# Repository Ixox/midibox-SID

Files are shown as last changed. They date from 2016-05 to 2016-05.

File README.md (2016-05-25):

# midibox-SID
PCBs, Panels and firmware for puting a 4 stereo voices midiboxSid in a 1U 19" rack

Contains all files needed for this project : 
http://midibox.org/forums/topic/20008-midibox-sid-rack-1u-project/

SID_CS/
Kicad files for the 1st surface control PCB

SID_CS2/
Kicad files for the 2nd surface control PCB

SID_MB/
Kicad files for the mother board

SID_MIXER/
Kicad files for the mixer PCB

midibox_sid_v2_044_rack1U/
Firmware: Thorsten source code with some modification for the rack 1U PCBs

pfm2_lib.pretty/
Kicad library

shaeffer/
Front Panel Designer files that work with this 1U rack : 
http://www.frontpanels.de/nrg-case-19-enclosures/

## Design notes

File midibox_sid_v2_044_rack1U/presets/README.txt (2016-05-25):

$Id: README.txt 398 2008-07-26 14:40:52Z tk $

This package contains the preset patches for MIDIbox SID V2:

   o v2_vintage_bank.syx:
     Based on "midibox_sid_presets_8580.syx" of the MBSID V1 preset library,
     converted with the patch converter which can be found in the tools/
     directory. The results have been manually improved by TK to take new
     V2 features into account.

Currently there is no special SysEx upload tool available for MIDIbox
SID V2. Please use a SysEx tool like MIDI-Ox, and configure a delay of
750 mS between SysEx strings (MIDI-Ox: SysEx->Configure, set "Delay after
F7 to 750 mS)

Following preset patches are available:
--------------------------------------------------------------------------------------------
001 Internal Patch      033 Drum Kit 1          065 ARPSEQ One B        097 Monty Lead3
002 Techno PWM          034 Drum Kit 2          066 ARPSEQ One C        098 Monty Lead4
003 Techno Saw          035 Drum Kit 3          067 SEQ TranceBass      099 Bassline Demo1
004 Techno 5th          036 Drum Kit 4          068 SEQ Vintage A       100 Bassline Demo2
005 Cool Brass          037 Some Triggs         069 SEQ Vintage B       101 Vib Synth
006 Simple Saw          038 More Triggs         070 SEQ Vintage C       102 Whats That?
007 Simple Pulse        039 RingModMod          071 ARPSEQ Two A        103 Sample&Hold 1
008 Pulse w/o Body      040 RampUp              072 ARPSEQ Two B        104 Sample&Hold 2
009 Popcorn             041 Math Game           073 ARPSEQ Two C        105 Curve Filter D
010 WT Flute            042 WT Runner           074 ARPSEQ Three        106 Curve total
011 Synth Plug          043 WT Stereo Echo      075 ARPSEQ Four         107 Poly Trancegate
012 WT Synth            044 Turntable           076 SEQ Mighty Bass     108 Zak Bass
013 WT HardcoreSynth    045 Driving a Car       077 Analog Dream1       109 Zak Bass 2
014 Sync Sound          046 Ufo Reverse         078 Analog Dream2       110 Kik A
015 Sync Pad            047 WT Falling          079 Analog Dream3       111 Cymbal A
016 Filt. Poly Pad      048 WT Helicopter       080 Analog Dream4       112 Cymbal B
017 Filt. Mono Pad      049 WT Neutron          081 Analog Dream5       113 Hat A
018 Arpeggio            050 WT Filtered Seq.    082 PWM Bass1           114 Snare A
019 Arpeggio 2          051 Alien Groove        083 PWM Bass2           115 Accomp A
020 WT Arp Fun          052 Nice Lead           084 PWM Bass3           116 Accomp B
021 Ringmodulation      053 NT Bass             085 PWM Bass4           117 Lead Stacco1
022 Filtered B. 6581    054 RingKabinett        086 Seq Bass1           118 Lead Stacco2
023 Filtered B. 8580    055 Random Fun          087 Seq Bass2           119 Lead Melodia
024 Filtered Bass 2     056 Don't cry baby!     088 Seq Bass3           120 Stacco4
025 C64 Bass            057 Tweak the LFOs      089 Seq Bass4           121 String Ponte 1
026 Autobahn            058 Random Sync         090 Seq Bass5           122 String Ponte 2
027 Bassdrum            059 A stormy Day        091 Seq Bass6           123 Crescendo
028 Bassdrum2           060 6 Octave Plug       092 Monty Bass1         124 Crazy Lead
029 Cymbal              061 Poly Saw            093 Monty Bass2         125 Accomp1
030 Klick               062 Step by Step        094 Monty Bass3         126 Casio Drums
031 Metal               063 Slow Intro          095 Monty Lead1         127 Classic Zelda
032 Deep Bass 9         064 ARPSEQ One A        096 Monty Lead2         128 Neo Zelda
--------------------------------------------------------------------------------------------

Patch 001-107 made by Thorsten Klose (2002-2004)
Patch 108-125 made by Matteo Bosi (2003-2004)
Patch 126-128 made by David Panseri (2004)

--------------------------------------------------------------------------------------------

ChangeLog:
~~~~~~~~~~

2008-07-26:
   o overworked patches for v2.0RC24 engine

2008-03-27:
   o replaced Placeholders A035 and A036 by new Drum Kits
   o replaced Placeholders A037..A044 by new trigger and modulation matrix examples
   o Patch A089-A91 (not working "Miami1"..3) replaced by "SEQ Bass 4"..6
   o Patch A103 and A104 (not working "WT Pseudo S&H") replaced by "Sample&Hold 1" and 2
   o Patch A107 (not working "WT Flip LFO") replaced by "Poly Trancegate"

2007-09-29:
   o Patch A033 and A034 replaced by Drum Kits + Sequences
   o Patch A035..A044 (expired WT drum patches) replaced by placeholders

2007-07-22:
   o Patch A099 and A100 replaced by Bassline demo sequences
     Recommented Ensemble configuration (Ensemble->INS)
       - Ins1 and Ins2 assigned to same MIDI channel
       - Ins1 splitpoints SpL: c-2, SpU: B-3
       - Ins2 splitpoints SpL: C-4, SpU: G-8
     Note that the second bassline can only be played if
     a second MBHP_SID module is connected to the core.

     Optionally within Ensemble->Clk the MIDI Slave function 
     can be activated.

2007-06-30:
   o released converted bank A for MIDIbox SID V2
	
2006-08-20:
   o new Patches C038-C048 made by Sebastian (aka Rio)
   o new Patches C049-C055 made by TK (they demonstrate the
     possibilities of the V1.7303 sound engine)
   o A018 (Arpeggio): changed Arp speed from 110 to 70
   o A019 (Arpeggio2): changed Arp speed from 110 to 70/90

2006-02-27:
   o new Patches C006-C037 made by Sebastian (aka Rio)

2005-11-09:
   o A018 (Arpeggio): changed Arp speed from 99 to 110
   o A052 (Nice Lead): changed Portamento speed from 66 to 30
   o A067 (SEQ TranceBass): optimized Attack/Decay/Curve of ENV1,
                            activated HP filter in addition
   o A074 (ARPSEQ Three): activated oscillator phase synchronization
   o A076 (SEQ Mighty Bass): changed ENV1 depth from 14 to 33
   o A078 (Analog Dream 2): increased Release of VCA ENVs
   o A080 (Analog Dream 4): increased Release of VCA ENVs
   o A089-A091 (Miami *): set volume to 80
   o A093/A094 (Monty Bass *): increased CutOff
   o A105 (Curve Filter D): increased CutOff
   o added Patch C006-C011 made by Sebastian (aka Rio)

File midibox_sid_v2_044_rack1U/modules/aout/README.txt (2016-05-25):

$Id: README.txt 1121 2013-04-16 20:18:49Z tk $

Driver for AOUT modules
=======================

Oversight
~~~~~~~~~

This driver provides functions to access DACs which are used in
the MIDIbox hardware platform (MBHP) to output analog control
voltages (MBHP_AOUT*).

The API is identical for all AOUT modules to allow highest flexibility. New
transfer protocols can be added w/o touching an existing application.

DAC and CS/CLK/DIN pin have to selected from the Makefile/Assembly source
during compile time.

Implementation Concept
~~~~~~~~~~~~~~~~~~~~~~

The application interface (API) has been tailored around AOUT modules, which
are part of the MIDIbox Hardware Platform (MBHP), and MIOS based applications
like MIDIbox CV (CV control via MIDI), MIDIbox SEQ (CV control from a 
sequencer) and MIDIbox SID/FM (CV control from a synthesizer)

Up to 8 analog outputs are supported (*)
An interface to control digital pins is available as well (**)

Output voltages are managed in 16bit resolution. Although none of the current
modules support the full resolution, from programming and performance
perspective it makes sense to organize CV values this way.

An additional function for setting pins in 7bit resolution is available,
which left-aligns the value to the 16bit format. The usage of this function is 
prefered for applications which are working at common MIDI resolution.

Before voltage changes are transfered to the external hardware, the 
AOUT_Pin16bitSet/AOUT_Pin7bitSet function compares the new value with the 
current one. If equal, the register transfer will be omitted, otherwise it
will be requested and performed once AOUT_Update() is called.

This method has two advantages:
   - if AOUT_Pin*bitSet doesn't notice value changes, the appr. AOUT channels
     won't be updated to save CPU performance
   - all CV pins will be updated at the same moment

(*) currently only limited by the AOUT_UPDATE_REQ variable. This could be enhanced 
in future if really required, but this would cost performance!

(**) currently only supported for MBHP_AOUT, since MAX525 provides such a digital output pin

Supported AOUT interfaces
~~~~~~~~~~~~~~~~~~~~~~~~~

AOUT_INTERFACE_TYPE == 0
   selects a dummy module which with empty function stubs (-> no external accesses)

AOUT_INTERFACE_TYPE == 1
   CV: up to 2 cascaded MAX525 (MBHP_AOUT module), each MAX525 provides 
   4 channels with 12bit resolution
   Digital: 1 pin per IC

AOUT_INTERFACE_TYPE == 2
   CV: up to 8 cascaded 74HC595 (each MBHP_AOUT_LC module provides 2 74HC595)
       resolution is selectable with AOUT_LC_RESOLUTION_OPTION_M1 .. 4:
       AOUT_LC_RESOLUTION_OPTION_Mx == 0: 12/4 bit configuration
       AOUT_LC_RESOLUTION_OPTION_Mx == 1: 8/8 bit configuration
       AOUT_LC_RESOLUTION_OPTION_Mx == 2: combines 4 shift registers. The first
          two SRs are working like option 0 (12/4). The third SR outputs the 
          lower bits of second channel, and the fourth SR the 8bit value of 
          third channel.
          The fourth channel value is ignored by this configuration
          (same for channel 4-7: channel 8 igored)
          For this "combined" option, it is recommented to set both modes
          (M1,M2 and/or M3/M4) to value 2 for future compatibility
   Digital: none

AOUT_INTERFACE_TYPE == 3
   CV: one TLV5630 (MBHP_AOUT_NG module) with 8 channels at 12bit resolution
   Digital: none

C usage examples
~~~~~~~~~~~~~~~~

  -> $MIOS_PATH/apps/processing/analog_toolbox

Assembler usage examples
~~~~~~~~~~~~~~~~~~~~~~~~

  -> $MIOS_PATH/apps/processing/midibox_cv
  -> $MIOS_PATH/apps/sequencers/*
  -> $MIOS_PATH/apps/synthesizers/*

Functions
~~~~~~~~~

See aout.inc for function descriptions
See aout.h for C declarations

Files
~~~~~

  aout.inc: toplevel of AOUT driver. Can be included into "asm-only" programs (non-relocatable code)
  sdcard.asm: relocatable wrapper for C based applications
  aout.h:   C header
  aout.mk:  include this into Makefile to integrate the module
  aout_*.inc: low-level drivers for the selected interface

Defines
~~~~~~~

  C programs (relocatable code): can be overruled with -D<define>=<value> from command line 
  Assembly programs: add #define statements within program before "#include <aout.inc>"

AOUT_INTERFACE_TYPE     ; 0..3, see description above

AOUT_LC_RESOLUTION_OPTION_M1  ; 0..2, see description above
AOUT_LC_RESOLUTION_OPTION_M2
AOUT_LC_RESOLUTION_OPTION_M3
AOUT_LC_RESOLUTION_OPTION_M4

AOUT_LAT_CS=LATC	; The chip select pin
AOUT_TRIS_CS=TRISC	; is connected to Port C.5
AOUT_PIN_CS=5		; (CANNOT be shared with other outputs!)

AOUT_LAT_DIN=LATC	; The data input pin DIN
AOUT_TRIS_DIN=TRISC	; is connected to Port C.4
AOUT_PIN_DIN=4		; (can be shared with other outputs)

AOUT_LAT_SCLK=LATD	; The shift clock input pin SCLK
AOUT_TRIS_SCLK=TRISD	; is connected to Port D.5
AOUT_PIN_SCLK=5		; (can be shared with other inputs)

Integration Hints
~~~~~~~~~~~~~~~~~

C based Applications
~~~~~~~~~~~~~~~~~~~~

  1) Makefile: add "aout.o" to OBJS variable

  2) Makefile: include aout.mk, and enhance AOUT_DEFINES if required:
---

# include SD Card Driver
# use following pin assignments:
AOUT_DEFINES += -DAOUT_INTERFACE_TYPE=1
AOUT_DEFINES += -DAOUT_LAT_CS=LATC -DAOUT_TRIS_CS=TRISC -DAOUT_PIN_CS=0
AOUT_DEFINES += -DAOUT_LAT_DIN=LATC -DAOUT_TRIS_DIN=TRISC -DAOUT_PIN_DIN=4
AOUT_DEFINES += -DAOUT_LAT_SCLK=LATD -DAOUT_TRIS_SCLK=TRISD -DAOUT_PIN_SCLK=5
include $(MIOS_PATH)/modules/aout/aout.mk
---

  3) main.c: #include <aout.h>

  4) main.c: add following code to Init() hook
---
  // initialize AOUT driver
  AOUT_Init();
---

  5) main.c: add following code to Tick() hook
---
  // update AOUT channels
  AOUT_Update();
---

"Assembler-Only" Applications
~~~~~~~~~~~~~~~~~~~~~~~~~~~~~

integration is possible, but not documented yet
However, most applications like MBCV, MBSID, MBFM, MBSEQ are using this driver!

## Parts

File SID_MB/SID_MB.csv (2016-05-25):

Reference | Value | Footprint | Datasheet
SID1 | 8580 | Housings_DIP:DIP-28_W15.24mm_LongPads
pic1 | PIC18f452 | Housings_DIP:DIP-40_W15.24mm
shft1 | 74HC595 | Housings_DIP:DIP-16_W7.62mm_LongPads
shft2 | 74HC595 | Housings_DIP:DIP-16_W7.62mm_LongPads
U2 | 24C512 | Housings_DIP:DIP-8_W7.62mm
U4 | 24C512 | Housings_DIP:DIP-8_W7.62mm
U5 | 24C512 | Housings_DIP:DIP-8_W7.62mm
C1 | LCD | Pin_Headers:Pin_Header_Straight_2x08
P3 | MEM | Pin_Headers:Pin_Header_Straight_2x02
C4 | 22nF | Capacitors_ThroughHole:C_Rect_L4_W2.5_P2.5
C5 | 22nF | Capacitors_ThroughHole:C_Rect_L4_W2.5_P2.5
P4 | SID_MEM | Pin_Headers:Pin_Header_Straight_1x02
R2 | 1k | Resistors_ThroughHole:Resistor_Horizontal_RM7mm
R4 | 100 | Resistors_ThroughHole:Resistor_Horizontal_RM7mm
C9 | 100nF | Capacitors_ThroughHole:C_Rect_L4_W2.5_P2.5
C10 | 100nF | Capacitors_ThroughHole:C_Rect_L4_W2.5_P2.5
C11 | 100nF | Capacitors_ThroughHole:C_Rect_L4_W2.5_P2.5
C12 | 100nF | Capacitors_ThroughHole:C_Rect_L4_W2.5_P2.5
P10 | IN1 | Pin_Headers:Pin_Header_Straight_1x02
P11 | IN2 | Pin_Headers:Pin_Header_Straight_1x02
P12 | STEREO OUT | Pin_Headers:Pin_Header_Straight_1x04
R9 | 1k | Resistors_ThroughHole:Resistor_Horizontal_RM7mm
C16 | 470pF | Capacitors_ThroughHole:C_Rect_L4_W2.5_P2.5
C14 | 1nF | Capacitors_ThroughHole:C_Rect_L4_W2.5_P2.5
Q1 | BC547 | TO_SOT_Packages_THT:TO-92_Molded_Narrow
C17 | 470pF | Capacitors_ThroughHole:C_Rect_L4_W2.5_P2.5
C15 | 1nF | Capacitors_ThroughHole:C_Rect_L4_W2.5_P2.5
Q2 | BC547 | TO_SOT_Packages_THT:TO-92_Molded_Narrow
C2 | 33pF | Capacitors_ThroughHole:C_Rect_L4_W2.5_P2.5
Y1 | 10Mhz | Crystals:Crystal_HC49-U_Vertical
C3 | 33pF | Capacitors_ThroughHole:C_Rect_L4_W2.5_P2.5
P7 | Midi Out | Pin_Headers:Pin_Header_Straight_1x03
P8 | Midi In | Pin_Headers:Pin_Header_Straight_1x03
R5 | 1k | Resistors_ThroughHole:Resistor_Horizontal_RM7mm
R6 | 1k | Resistors_ThroughHole:Resistor_Horizontal_RM7mm
R10 | 1k | Resistors_ThroughHole:Resistor_Horizontal_RM7mm
R7 | 10k | Resistors_ThroughHole:Resistor_Horizontal_RM7mm
R8 | 10k | Resistors_ThroughHole:Resistor_Horizontal_RM7mm
R14 | 220 | Resistors_ThroughHole:Resistor_Horizontal_RM7mm
R15 | 220 | Resistors_ThroughHole:Resistor_Horizontal_RM7mm
R16 | 220 | Resistors_ThroughHole:Resistor_Horizontal_RM7mm
D1 | 1N4148 | Diodes_ThroughHole:Diode_DO-35_SOD27_Horizontal_RM10
R12 | 1.2k | Resistors_ThroughHole:Resistor_Horizontal_RM7mm
R13 | 5.6k | Resistors_ThroughHole:Resistor_Horizontal_RM7mm
RV1 | POT | Encoder:FMRV
R11 | 68 | Resistors_ThroughHole:Resistor_Horizontal_RM7mm
P2 | MEM_sel | Pin_Headers:Pin_Header_Straight_2x02
U3 | 24C512 | Housings_DIP:DIP-8_W7.62mm
P13 | J11 | Pin_Headers:Pin_Header_Straight_1x02
P14 | CAN | Pin_Headers:Pin_Header_Straight_1x02
R17 | 1k | Resistors_ThroughHole:Resistor_Horizontal_RM7mm
D2 | 1N4148 | Diodes_ThroughHole:Diode_DO-35_SOD27_Horizontal_RM10
C6 | 22nF | Capacitors_ThroughHole:C_Rect_L4_W2.5_P2.5
C7 | 22nF | Capacitors_ThroughHole:C_Rect_L4_W2.5_P2.5
R1 | 1k | Resistors_ThroughHole:Resistor_Horizontal_RM7mm
opt2 | 6n138 | Housings_DIP:DIP-8_W7.62mm
P6 | J9 J8 | Pin_Headers:Pin_Header_Straight_2x05
C13 | 100nF | Capacitors_ThroughHole:C_Rect_L4_W2.5_P2.5
SID2 | 8580 | Housings_DIP:DIP-28_W15.24mm_LongPads
P1 | 9V | Connect:bornier2
P9 | 5v | Connect:bornier2
CP1 | 10uF | Capacitors_ThroughHole:C_Radial_D5_L6_P2.5
CP2 | 10uF | Capacitors_ThroughHole:C_Radial_D5_L6_P2.5
R3 | 10k | Resistors_ThroughHole:Resistor_Horizontal_RM7mm
C8 | 100nF | Capacitors_ThroughHole:C_Rect_L4_W2.5_P2.5
C18 | 100nF | Capacitors_ThroughHole:C_Rect_L4_W2.5_P2.5
H1 | 3mmHole | Mounting_Holes:MountingHole_3.2mm_M3
H2 | 3mmHole | Mounting_Holes:MountingHole_3.2mm_M3
H3 | 3mmHole | Mounting_Holes:MountingHole_3.2mm_M3
H4 | 3mmHole | Mounting_Holes:MountingHole_3.2mm_M3
CP3 | 1uF | Capacitors_ThroughHole:C_Radial_D5_L6_P2.5
CP4 | 1uF | Capacitors_ThroughHole:C_Radial_D5_L6_P2.5
C20 | 1nF | Capacitors_ThroughHole:C_Rect_L4_W2.5_P2.5
C19 | 1nF | Capacitors_ThroughHole:C_Rect_L4_W2.5_P2.5
DB1 | Diode_Bridge | Gajda_power:Bridge-rond
CP5 | 2200uF | Capacitors_ThroughHole:C_Radial_D12.5_L25_P5
C21 | 330nF | Capacitors_ThroughHole:C_Rect_L4_W2.5_P2.5
CP6 | 10uF | Capacitors_ThroughHole:C_Radial_D5_L6_P2.5
C22 | 100nF | Capacitors_ThroughHole:C_Rect_L4_W2.5_P2.5
DB2 | Diode_Bridge | Gajda_power:Bridge-rond
CP7 | 2200uF | Capacitors_ThroughHole:C_Radial_D12.5_L25_P5
C23 | 330nF | Capacitors_ThroughHole:C_Rect_L4_W2.5_P2.5
CP8 | 10uF | Capacitors_ThroughHole:C_Radial_D5_L6_P2.5
C24 | 100nF | Capacitors_ThroughHole:C_Rect_L4_W2.5_P2.5
U6 | 7809 9v | Power_Integrations:TO-220
U1 | 7805 5v | Power_Integrations:TO-220
P15 | 9VOnly | Pin_Headers:Pin_Header_Straight_1x02
P5 | J5A | Pin_Headers:Pin_Header_Straight_2x06
P16 | J5B | Pin_Headers:Pin_Header_Straight_1x03

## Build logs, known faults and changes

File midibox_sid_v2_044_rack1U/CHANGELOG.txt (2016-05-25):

$Id: CHANGELOG.txt 1189 2014-12-19 20:00:14Z tk $

MIDIboxSID V2.044
~~~~~~~~~~~~~~~~~

   o This version got an improved rotary encoder handling.
     Please update to MIOS V1.9h before uploading the application, otherwise the improvements
     won't be effective.

   o swapped behaviour of ENC speed control again, so that encoders are at fast speed
     by default, and slow if SHIFT button pressed.
     This behaviour can now be alternated in your setup_*.asm file by changing
     the DEFAULT_SHIFT_SPEED_CONTROL_MODE option

   o implemented special encoder testmode which can be enabled with
     DEFAULT_TESTMODE_ENC_SPEED in the setup_*.asm file

   o envelopes are now released properly when a note is played via the SysEx editor
     (or with the PLAY button)

   o added new "SuperSaw" detune mode which has been created by Lis0r.
     In distance to the normal (legacy) mode, results are much better especially on
     higher detune values!
     The detune mode (DtM) can be selected in the OSC page for lead engine patches, and
     in the O23 page for bassline patches.

MIDIboxSID V2.043
~~~~~~~~~~~~~~~~~

   o fixed NRPN handling for Multi patches

   o implemented CCs for Bassline/Drum/Multi Engine
     See doc/mbsidv2_cc_chart.txt for available CCs

   o display updated when the patch name has been changed from external

MIDIboxSID V2.042
~~~~~~~~~~~~~~~~~

  o new SysEx commands to support the Lemur Editor

  o MIDI Clock is now optionally sent with the "Out" option of the Ensemble Clk page.

  o default encoder mode is "DETENTED3" now, since it works better for most encoders
    available on the market

  o swapped behaviour of ENC speed control: encoder now at fast speed if SHIFT button is pressed

MIDIboxSID V2.041
~~~~~~~~~~~~~~~~~

  o corrected sysex handling for MIOS Studio SysEx Librarian

MIDIboxSID V2.040
~~~~~~~~~~~~~~~~~

  o fixed SysEx patch write issue which happened when patches were received
    with the common format (e.g. preset patches)

MIDIboxSID V2.039
~~~~~~~~~~~~~~~~~

  o LFO MIDI Clock Sync has been overworked, it now supports 32 different
    rates from 16 bars to 1/32 notes including triple and dotted delays!

    If the CSn flag enabled the available rates are:
    0=LFO disabled, 8=16 bars, 16=14 bars, 24=12 bars, 32=10 bars,
    40=9 bars, 48=8 bars, 56=7 bars, 64=6 bars, 72=5 bars, 80=4 bars,
    88=3.5 bars, 96=3 bars, 104=2.5 bars, 112=2 bars, 120=1.5 bars,
    128=1 bar, 136=1/2., 144=1/1T, 152=1/2, 160=1/4., 168=1/2T,
    176=1/4, 184=1/8., 192=1/4T, 200=1/8, 208=1/16., 216=1/8T,
    224=1/16, 232=1/32., 240=1/16T, 248=1/32

    Note that in MIDI Sync mode, the LFO Delay won't work because
    the appr. resource is used as MIDI clock counter.

  o current bank and patch number won't be changed anymore on direct RAM
    access via SysEx

MIDIboxSID V2 RC38
~~~~~~~~~~~~~~~~~~

  o optimized MBNet Handler for fast external access to SID registers

  o added DEFAULT_CC32_FILTER switch to setup_*.asm - it filters CC#32 for
    programs which send this CC always together with CC#0 on bank changes

  o support for "extended SysEx dump" - see also mbsidv2_sysex_implementation.txt

  o filter mode/channel and waveform flags can now be optionally passed to 
    J5 (configuration has to be done in setup_*.asm file)

  o (only for Multi Engine): "W+16" flag - waveform can be changed from
    offset +16 of the wavetable, in combination with another parameter
    (such as #249), it's possible to control pitch and waveform from
    a single WT track

MIDIboxSID V2 RC37
~~~~~~~~~~~~~~~~~~

  o SW based feedback loops won't lead to endless repeated replies

MIDIboxSID V2 RC36
~~~~~~~~~~~~~~~~~~

  o Bassline engine: detune parameter now mapped to Parameter #003
  o a table based calibration table is now provided for the SID filter.
    It has to be adapted under src/sid_filter_table.inc and can either be
    uploaded together with the firmware build, or separately if by uploading
    "sid_filter_table.hex" after the "make" command (type "make sid_filter_table"
    to build only this file)
    The table can be used to compensate technology related non-linearities
    of the 6581 R-2R DAC
  o various minor bugfixes

MIDIboxSID V2 RC35
~~~~~~~~~~~~~~~~~~

  o modulation source "KEY" now uses current frequency instead of key number
    to consider frequency sweeps correctly
  o bugfix for "jump to page" (empty page if current item position outside new page)
  o bugfix for knob page (min/max value modified Pa1 if multiple SIDs selected)

MIDIboxSID V2 RC34
~~~~~~~~~~~~~~~~~~

  o fixed race condition in SusKey portamento function
  o Note Off keys which are not in the note stack are ignored now
  o implemented CC#123 (All Notes Off)
    Complies to MIDI spec. Means: only CC#123=0 will unplay all notes,
    all other values (1..127) are silently ignored
  o new wavetable control function "Key" allows to select a wavetable
    step with the currently played note inside the given Begin/End range.
    E.g., with Begin=0x00, End=0x7f, KEY=on, Par=200 you are able to
    define different ENV1 Decay parameters for each note.
    There are much more usecases of course (e.g. different LFO values,
    different waveforms, Sync/Ring enable/disable in certain keyranges)
    - be creative :)
  o Arpeggiator "Easy Chord" function now active in default Lead/Bassline/Multi
    patch
  o sammichSID: F2 button now jumps to Knob page by default (especially
    nice for bassline patches, for other engines the knob assignments
    are mostly not preconfigured)
  o Multi Engine: Knob parameter #6 and #7 now allow to control CutOff
    frequency of left/right channel SID separately. Note that this isn't
    consistent to Lead/Bassline assignments, but unfortunately there is
    no other possible solution.
  o filter page now allows direct L/R channel selection
  o the full control surface now handles the first press of Osc Select, 
    Env Select, LFO Select and Filter Mode/Channel Select as a 
    "jump to page" function if that page was not displayed, and 
    thereafter, function as a "change selection" function. Thus 
    if you are not on the LFO page, pressing LFO Select jumps to 
    LFO page, and then pressing it again will change the selected LFO.
  o this is the christmas edition, therefore the Matrix LEDs are flickering
    during startup ;-)

MIDIboxSID V2 RC33
~~~~~~~~~~~~~~~~~~

  o built for MIOS V1.9g (or higher) to support new encoder types.
    Rotary encoders won't work with older MIOS versions!
    Note that MIOS only has to be updated on the master SID, as encoders
    are not connected to SID slaves anyhow.
  o a new LED matrix visualisation mode for sammichSID has been added
    which is selected with DEFAULT_LEDMATRIX_MODE 2
    - Lead and Bassline engine: 6x8 LEDs show VU meters for OSC frequency
    - Multi and Drum engine: 6x8 LEDs show animated VU meters for OSC triggers
    - ASID player mode: 6x8 LEDs show animated VU meters for OSC triggers
  o animated VU meters are a bit faster now
  o a special configuration file and prebuilt binary for sammichSID 
    is now part of the release package -> setup_sammich_sid.hex

MIDIboxSID V2 RC32
~~~~~~~~~~~~~~~~~~

  o fixed strange Oct display output in Bassline Sequence Editor
  o added "DEFAULT_ENABLE_UPPER_WAVEFORMS" switch to setup_* files to enable the
    selection of additional waveforms for SwinSID
  o overworked Meter display mode in Bassline Mode (enjoy the effect! :)
  o changed behaviour of Play button: now it plays all SIDs regardless if they
    are selected or not.
    Dedicated SIDs can be played by pressing & holding the appr. SID buttons
    before pressing PLAY

MIDIboxSID V2 RC31
~~~~~~~~~~~~~~~~~~

  o fixed storing ensemble in internal EEPROM if no BankStick selected
  o the ensemble stored in internal EEPROM (previously called E001) is now called EInt
  o the patch stored in internal EEPROM (previously called [A-H]001) is now called PInt
  o EInt now automatically selected after startup if no ensemble BankStick connected
  o E002 now automatically selected after startup if EInt was selected before
  o fix for communication with Rutger's SysEx editor: mod matrix direct assignments
    are handled correctly now in stereo edit mode

MIDIboxSID V2 RC30
~~~~~~~~~~~~~~~~~~

  o fixed OSC button behaviour (OSC selection corrupted on page changes)

MIDIboxSID V2 RC29
~~~~~~~~~~~~~~~~~~

  o fixed CC#07 (now controls volume as intended)
  o for 4x20 LCD: MIDI channels and Engines of selected ensemble are displayed at upper line
  o OSC button now cycles between 1--, -2-, --3 and 123
  o added optional CS_MENU_BUTTON_Arp function, which can be assigned to a button in setup_*.asm

MIDIboxSID V2 RC28
~~~~~~~~~~~~~~~~~~

  o fixed arpeggiator note handling bug
  o arpeggiator: the previously hardcoded "experimental arp behaviour" switch is now 
    available as software controlable switch called "Easy Chord".
    It has to be enabled in the ARP menu ("Esy" flag)
    Difference compared to normal chord entry: depressed keys will still
    be cylced by the arpeggiator until a new key is pressed.
    This feature is especially useful when slow arpeggios are played, since
    it avoids unintended "long notes" on chord changes.
    It is not useful if you intend to play a voice like a common lead instrument,
    which should turn into a fast arpeggio when more than one key is played
    (in this case, ensure that the "Esy" switch is disabled)
  o fixed drum model handling (listen to the drum patches again - they sound much better now :)
  o preliminary support for parameter access via 7bit CC
    (only available for Lead Engine yet)

MIDIboxSID V2 RC27
~~~~~~~~~~~~~~~~~~

  o Super Poly voice queue now handled centrally from master.
    Slaves notes are triggered via MBNet
  o SPV value now changed simultaneously for all slaves
    It can only be changed if master SID selected
  o PLAY button now plays a chord in superpoly mode
  o Mod matrix changes forwarded to all selected SIDs

MIDIboxSID V2 RC26
~~~~~~~~~~~~~~~~~~

  o various improvements for Super Poly Mode and SysEx distribution via CAN

MIDIboxSID V2 RC25
~~~~~~~~~~~~~~~~~~

  o improved "SusKey" (fingered portamento) handling

MIDIboxSID V2 RC24
~~~~~~~~~~~~~~~~~~

  o voice allocation of multi engine working again
  o Lead engine: MdW (ModWheel) and Key modulation source now provide a value in
    positive range only
  o overworked oscillator pitch handling: now completely linear frequency
    calculations. 
    Advantages:
      - modulation frequency (e.g. LFO vibrato) independent from oscillator frequency
      - accurate filter key tracking
      - the O2A option (forward pitch to AOUT) doesn't result into out-of-scale
        SID frequencies anymore
  o the presets under presets/v2_vintage_bank.syx have been overworked according to
    the new osc frequency handling

MIDIboxSID V2 RC23
~~~~~~~~~~~~~~~~~~

  o finetune is working properly again

MIDIboxSID V2 RC22
~~~~~~~~~~~~~~~~~~

  o "menu labels" (activated if DEFAULT_LCD_LINES >= 3) now completely implemented
  o added keyboard transpose function for bassline sequencer. MIDI channels and
    keyboard zones have to be configured for L/R bassline separately with
    ensemble instrument 3 and 4. The transposer uses C-3 as base note.
    Example configuration:
    Ins1 Chn 1 SpL C-3 SpU B-3 Trn 0     L Bassline sequence selected with key C-3..B-3
    Ins2 Chn 1 SpL C-4 SpU G-8 Trn 0     R Bassline sequence selected with key C-4..
    Ins3 Chn 1 SpL c-2 SpU B-2 Trn +12   L Bassline sequence transposed with lower keys until B-2
    Ins4 Chn 1 SpL c-2 SpU B-2 Trn +12   R same as for L
    "Trn +12" is required in this setup to compensate the octave range of the transposer
    (base note C-3 is outside the selected keyboard zone c-2..B-2)
  o bassline and drum sequences not stopped anymore on patch changes
  o random generator for bassline O23 settings

MIDIboxSID V2 RC21
~~~~~~~~~~~~~~~~~~

  o added "Log" flag to ENS->FIL menu: cutoff frequency converted through log function
    to achieve better linearisation of 8580 filter
  o Filter Keytracking parameter now also available for Lead Engine, the scaling has been slightly
    changed, so that the maximum value 255 leads to 1:1 tracking (e.g. if 8580 Log function activated,
    or an external filter is connected)
  o added "DOR" flag to the ENS->SID menu: Disable automatic Oscillator Reset during patch change
    could also be called DAORDPC flag ;-)
  o MB-6582 setup: swapped page up/down button, added Inc/Dec button function
  o support for 4x20 LCD has used for MB-6582: DEFAULT_LCD_LINES and DEFAULT_LCD_LINE_Y* can
    be configured in the setup_*.asm file
  o MB-6582 screen now centered at 2nd and 3rd line
  o if DEFAULT_LCD_LINES >= 3, the name of the menu will be print at the upper line
  o if DEFAULT_LCD_LINES >= 4: the value of the currently edited parameter will be displayed
    as horizontal bar graph at the lower LCD line
    TODO: display bidirectional parameters like "depth" with a left/right splitted graph
    TODO: update when a new OSC/Channel/SID is selected
  o the "blinking LCD cursor" which was set to the selected parameter position is
    disabled by default now (DEFAULT_LCD_PRINT_CURSOR set to 0), since it clashes with
    the horizontal bar graph output routine
  o added experimental features to bassline engine:
    - new menu page O23 which allows to use OSC2 and OSC3 as slave oscillators
    - waveforms of slave oscillators can be selected separately
    - individual sync and ringmod flags
    - individual octavewise transpose
    - individual pulsewidth
    - optional static note (decoupled from master osc) for nice sync/ringmod effects or chords
    - phase offset
    - detune
    - TODO: Knob assignments and maybe more functions

MIDIboxSID V2 RC20
~~~~~~~~~~~~~~~~~~

  o Multi Engine: arp handler working properly again
  o Lead Engine: ENV encoder section working properly again
  o increased startup delay, so that slave cores will be found even if no BankStick connected

MIDIboxSID V2 RC19
~~~~~~~~~~~~~~~~~~

  o Enhancements for SysEx Editor
    (see also doc/mbsidv2_sysex_implementation.txt)
    - introduced <WOPT> function which allows to change parameters of
      multiple voices with a single SysEx command
    - introduced <sids> selection which allows to access slave SIDs
      via master SID (command 0C 00 <sids>)
    - added SysEx command for all notes/sequences off (command 0C 08)
    - added SysEx command to play the current patch (command 0C 09 [<ins>])
      Note: for proper handling of <ins>, separate keyboard zones or MIDI channels
      for multi instruments are currently required - this is no bug, 
      but just an imperfection (I was too lazy to overwork SID_PATCH_NotesOn yet)
  o parameter assignment/patch/bank selection: "big message" now displayed
    immediately when menu item has been selected
  o The "note off" function of the SHIFT menu now works as "Note On/Off" (called "Ply")
    This function is intended as replacement for the optional Play button
    Patch will be played/stopped on all selected SIDs
  o Removed button combination "SIDx+MENU" (which was previously used for Play function)
    This combination could get a different purpose on future
  o LFOs and ENVs of right channel bassline working properly again
  o AOUT_LC driver now supports 12/12/8 resolution (requires 4 combined 74HC595)

MIDIboxSID V2 RC18
~~~~~~~~~~~~~~~~~~

  o modulation matrix: comparison operators >, < and = now return 0 instead
    of full negative value if comparison is false
  o changed SusKey handling, so that it also works in Mono mode (previously
    it was only working in Legato mode)
  o SusKey and Legato flags now accessible in Bassline CFG menu
  o Individual Attack/Decay/Release Curve assignments now accessible in
    Multi/Bassline ENV menu
  o Trigger Matrix: since the BPM clock generator concept has been changed in
    one of the previous releases, we now have a Clk/6 and Clk/24 trigger instead
    of Clk/4 and Clk/16
  o LFO and ENV MIDI sync working properly again
  o portamento omitted after patch change when first key is played

MIDIboxSID V2 RC17
~~~~~~~~~~~~~~~~~~

  o switched from MPASM to gpasm
    code now under version control (SVN)

MIDIboxSID V2 RC16
~~~~~~~~~~~~~~~~~~

  o "ENV Misc" layer added for MB6582 Control Surface
  o SIDPlayer: lower line now always cleared when new LCD message
    is sent by host
  o changed encoder speed behaviour: values incremented fast by
    default now. Incrementer is slowed down by pressing the SHIFT button
    (previously it was the opposite behaviour)

MIDIboxSID V2 RC15
~~~~~~~~~~~~~~~~~~

  o improved FIP function (linear interpolation of filter cutoff) - it
    is working now the same way as implemented in MIDIbox CV
  o F2A and V2A flags moved to new storage position in ensemble - old
    ensemble setups (where F2A and/or V2A was set) have to be adapted!
  o added new AOUT forwarding functions:
     - P2A (Pulsewidth-to-AOUT)
     - K2A (Key-to-AOUT)
     - O2A (Oscillator Frequency-to-AOUT)
    Channel assignments have to be adapted in setup_*.asm - all channels 
    are disabled by default
  o added functions to forward the 6 gates/slide/accent signals to the
    digital outputs at J5. Assignments have to be configured in the
    setup_*.asm file.
    Note that DEFAULT_J5_FUNCTION has to be set to 3 in order to
    enable the digital output function of CORE:J5

MIDIboxSID V2 RC14
~~~~~~~~~~~~~~~~~~

  o BankStick write via SysEx now gracefully aborted if only 32k BankStick
    is addressed and patch number >= 065
    SysEx error number 0x11 ("BankStick too small") will be returned in this case
  o the "send dump" function of the "shift menu" now sends the edit buffer
    of the selected SID, which also includes the corresponding device ID.
    BankStick content won't be overwritten if such a dump is sent back.
  o menu page automatically changed to the previous selection if SID master
    or slave selected which is running with a different engine

MIDIboxSID V2 RC13
~~~~~~~~~~~~~~~~~~

  o multi engine: improved approach for routing LFOs to filters (only
    LFO of last assigned voice will be used for more predictable results)
  o reduced intensity of LFO pitch modulation for multi and bassline engine
    (Lead engine: intensity can be reduced by decreasing the depth
    of the modulation path)
  o 8 external switches can now be connected to 
     - DOUT shift register (-> DEFAULT_EXT_SWITCH_DOUT != 0)
     - port J5 of the core mode (-> DEFAULT_J5_FUNCTION == 3)
    The switch states are stored in the patch structure, and
    can be accessed via Control Surface (EXT menu) or via Parameter Change
    (NRPNs/Knobs/Wavetables)
  o support for dumping ensembles via SysEx
  o the SysEx structures are now completely documented under
    doc/mbsidv2_sysex_implementation.txt

MIDIboxSID V2.0 Initial Beta History (RC13)
~~~~~~~~~~~~~~~~~~~~~~~~~~~~~~~~~~~~~~~~~~~

   o created patch structure for Lead engine
   o removed old sound engine, the new one will be built up from scratch
   o overworked control surface handler - now we can control left and
     right SID channel separately (or together)
   o press and hold LINK button to select the SID channel (left/right) with GP button #1
   o this menu also allows to send a patch via SysEx
   o new patches can now also be received - this is important during
     development phase to store/restore sound patches via MIDI-Ox
   o Portamento effect implemented - "normal" and "constant time glide" CTG
     CTG can be selected in the OSC menu (PMd item)
   o A third portamento effect implemented: Glissando (PMd item: "Gls")
   o SusKey and Legato implemented (-> CFG menu)
   o LFO implemented - in addition to Sine/Triangle/Saw/Pulse/Random
     now also "Positive" Sine/Triangle/Saw/Pulse is available - they
     can be inverted with negative depth
   o menu items with toggle function now never go into "entry" mode
     where parameter has to be modified with datawheel - this is for
     faster usage
   o implemented modulation matrix:
     - there are 8 modulation paths
     - each path has two sources: ENV1..2, LFO1..LFO6, Constant 0-127 - much more will be added later
     - an operation parameter is available for each path:
       SRC1 only, SRC2 only, SRC1+SRC2, SRC1-SRC2, SRC1*SRC2, XOR, OR, AND, MIN, MAX, 1<2, 1>2, 1=2)
     - a depth parameter is available for each path
     - paths can be routed to Pitch Voice 1/2/3, Pulsewidth Voice 1/2/3,
       Filter and Volume of left/right SID separately
     - in addition they can be routed to 2 individual targets 
       LFO1-6 Rate, LFO1-6 Depth
       More (e.g. ENV parameters) will be added later
     - Target 1/Left Channel and Target 2/Right Channel subpath can
       be inverted for simple stereo effects
   o added pulsewidth as modulation target
   o ENV implemented - it provides the parameters 
     Attack1/ALevel/Attack2/Decay1/DecayLevel/Decay2/Sustain/Release1/
     ReleaseLevel/Release2 + Curve for Attack/Decay/Release phase
   o added filter as modulation target
   o filter of both SIDs now calibratable, settings stored in internal EEPROM
   o mod matrix + meter display working
   o init patch function implemented (press & hold LINK button)
   o random function implemented (press & hold LINK button)
   o added LFO Rate and Depth as modulation target
   o the sound won't stop anymore if a note is played during the 
     patch is changed/initialized/randomized - instead, the new sound
     will be played
   o support for slave SIDs (access via MBNet)
   o new operations: 1<2, 1>2, 1=2
   o added Volume 1/2 as modulation target
   o Note, LFO and ENV delay implemented
     LFO delay and phase only takes effect when sync flag set (not freerunning)
   o LFO oneshot mode implemented
   o implemented global clock generator
     Since there is no free timer resource, it's realized as a clock
     divider, which is incremented on each update cycle (819.2 uS)
     A clock event will be trigger each time the clock divider value
     has been reached. 
     Div=1 -> event all 1*819.2 uS
     Div=2 -> event all 2*819.2 uS = 1.6 mS
     Div=3 -> event all 3*819.2 uS = 2.5 mS
     etc...
   o optionally the clock generator can be used as MIDI clock receiver
     (Mod: Slv) - the MIDI clock can be divided as well
     Div=3  -> event all 32th notes
     Div=6  -> event all 16th notes
     Div=12 -> event all 8th notes
     Div=24 -> event all 4th notes
     etc...
   o "Mod: Auto" not implemented yet - should switch automatically to
     slave mode when a MIDI clock is received
   o implementation of Arpeggiator has started
     it is located in a separate menu now
     each voice has its own arpeggiator with own parameter sets (!)
     it's clocked by the global clock generator
     Spd divides the global clock again
     GLn (Gatelength) defines, at which clock between 1 and Spd the
       gate will be released
     Rng defines the octave range
   o Arp: added Up/Down/U&D/D&U/UD2/DU2/Random direction
   o Arp: added Sorted mode
   o Arp: added Hold mode
   o Arp: added "sync divider" mode
     - if disabled, the clock divider will be reset with a new chord, so
       that the arp starts immediately - perfect for live playing
     - if enabled, the clock divider won't be reset, so that it is always
       in synch with the global clock generator - perfect for MIDI slave mode
   o "Constant Arp Cycle" implemented
   o Velocity, Aftertouch, PitchBend, Keynumber, Knob #1-5 now
     available as modulation source
   o Knobs controllable via CC
     - Knob #1 assigned to CC#1 (ModWheel)
     - Knob #2-5 assigned to CC#16-19
   o Modulation parameters for Knobs (and Velocity=K#V,
     Aftertouch=K#A, PitchBender=K#P) are set within the Min/Max
     boundaries, which can now be edited in the new KNB menu page
     Note that sweeps from -128..127 and 127..-128 (swapped) are
     provided
   o Knob#1-Knob#5 now controllable directly from the CS Step C
     with the 5 rotary encoders of the oscillator section (select
     "Assign" layer)
   o removed "Balance" parameter, as it is redundant
     Can be realized with:
     MOD SRC1:K#1 In1:*, In2:o, Dep:127, Vol: L/R
   o support for AOUT/AOUT_LC
     - offset values (12 bit, 000-FFF) can be configured in new EXT menu
   o note: EXT (external) could also be read as "extension", because it
     the 12bit values could also be used for different purposes ("custom
     values")
   o implementation of trigger matrix
     It consist of 16 sources and 24 targets
     Sources are:
       Note On, Note Off, ENV1/2 Decay Phase, ENV1/2 Sustain Phase,
       LFO1-6 Period, Clock, Clock/4, Clock/16, MIDI Start
     Targets are:
       OSC1-3 L/R Gate (6 targets), ENV1/2 Attack, ENV1/2 Release,
       LFO1-6 Restart, Wavetable 1-4 Reset, Wavetable 1-4 Step
   o Trigger matrix connections can be configured in new TRG menu
   o Note that old patches have to be adapted the following way:
       - Note On: all 6 gates and ENV1/2 attack phase have to be assigned
       - Note Off: all 6 gates and ENV1/2 release phase have to be assigned
       - MIDI Start: ENV1/2 Attack and LFO 1-6 have to be assigned
       - the formerly LFO sync flag has now a new location in the trigger
         matrix. It has to be assigned in the Note On source. This can
         also be done from the LFO menu (shortcut for this TRG matrix connection)
   o Example 1 - LFO Chain:
     Assign all LFOs to OSC Pitch
     All LFOs in Oneshot Mode
     Use different LFO rates and depths
     Enable following Trigger connections:
        Note On->L1
        L1P -> L2
        L2P -> L3
        L3P -> L4
        L4P -> L5
        L5P -> L6
        L6P -> L1
   o Example 2 - ENV Retrigger via LFO1:
     Assign ENV1 to OSC Pitch
     Disable the Note On -> E1A connection
     Enable the LFO1 -> E1A connection
     Try different LFO1 rates and ENV A/D/S rates
   o Example 3 - Note Retrigger via LFO1:
     Enable the LFO1 -> O1L and O1R connection
     Try different LFO1 rates
     Try different OSC ADSR values (e.g. A=8, D=5, S=0, R=0) - remind the ADSR bug! :-/
     Try also different Delays between Left and Right SID
   o Example 4 - Simple ENV loop:
     Enable the E1S -> E1A connection
     Now ENV1 will loop between the attack and sustain phase
  o new button functions:
      - Link button now controls SHIFT function (and displays CFG page)
      - CC button now used as Page Up function (increments OSC/LFO/ENV/MOD/TRG/KNB depending on menu)
      - Edit button now used as Page Down function (increments OSC/LFO/ENV/MOD/TRG/KNB depending on menu)
      - Page Up/Down + datawheel (main encoder) allows to change the page via encoder
      - CC can be activated by pressing SHIFT+CC
      - Edit can be activated by pressing SHIFT+EDIT
      - SHIFT+E1/E2/L1..L6 button branches to the Envelope/LFO menu
  o SHIFT button now increases the speed of rotary encoders
  o added phase offset synchronisation feature
    Phases of the oscillators can be shifted in 0.4% steps!
    There is only one global phase available, which can be configured
    in the OSC menu. If != 0, the value specifies the phase offset
    between OSC1->OSC2 and OSC2->OSC3
  o added F2A (Filter to AOUT) function which allows to forward
    CutOff/Resonance to 4 AOUT channels (assignments are defined in setup_*.asm)
  o implemented knob parameters:
    - list of parameters can be found in mbsidv2_parameter_chart.txt
    - note that some parameters are not really suitable for live
      control - the table has been prepared for the WT handler, which
      will use the same parameter set
    - two different parameters can be assigned to a knob
    - the LCD shows the parameter in long format when the assignment is changed
      (selecting the item with a button does not already show the long format.
       I tried this, but the behaviour was too confusing... - you need to move
       the encoder to see the purpose of the value)
    - the handler automatically scales the knob value to the range of the
      target parameter. Regardless if a 4bit or a 12bit value should be controlled,
      the whole knob range from 0..255 will always be used
    - in addition, the knob range can be scaled a second time from a
      min to a max value
    - The formula:
         resulting parameter value = scale1(scale2(knob value))
      where scale2() scales over the specified min/max range
      and scale1() scales over the parameter range
    - Sounds confusing? Try this: Min=104, Max=152, Pa1=36 (Transpose OSC123)
      This will modify the 7bit value transpose from -12 to +12 notes
      (*2 because it's transposed from a 8bit value)
      Resp.: 128 +/- (2*12)
    - note that knob changes are non-destructive!
      This means: changing a parameter will not change the original value. 
      Accordingly the value visible in the CS menu will stay the same.
      This is especially required to ensure, that changes made with knobs
      are really temporary and won't be stored with the "patch save" function.
    - OSC/Filter parameter changes are always applied on both SID channels. 
      Offset calculations are done separately
    - TODO: "reset original value" function, accessible from the CFG menu,
      to remove the offsets from the original parameter values
  o implemented wavetable handler:
    - there is a WTC (Wavetable Configuration) and a separate WTE
     (Wavetable Edit) menu for easier navigation
    - it is possible to jump from WTC to WTE and back (last menu item)
    - WTC provides four different wavesets. 
      You can specify a parameter, SID L/R, Speed (Clock Divider for
      clock events coming from the trigger matrix),
      begin, end and loop position (with optional oneshot mode) within wavetable
    - WTE allows to edit the wavetable like known from MBSID V1
      Even Notes and ARPs can be played :)
    - WTE value display can be changed between Hex/Dec view
    - wavetable values are forwarded to MOD matrix as additional sources
    - the wavetable pointer can be optionally controlled from the
      modulation matrix. For this, the "MOD" flag has to be set in
      the WTC menu. In this mode, the clock divider and loop pointer
      don't play a role anymore. WT1-WT4 are available as modulation
      target, the pointer is swept between the begin and end range.
      Try to control the position with a LFO or an Envelope or the 
      velocity, and have fun! :)
  o there is now a new random generator menu which allows to randomize
    different sections of a patch separately
  o LFOs and ENVs can now be synchronized to the global clock (CSn flag)
    This clock is quadrubled to achieve better resolutions when it is
    synchronized to MIDI
    With Div=3, the LFO/ENV will be clocked 4 times for each 32th note,
    8 times for each 16th, 128 times for each measure...
    
    There are predefined rates for MIDI clock synchronisation, which
    can be selected in the LFO page when CSn is enabled
    They are starting at rate=245:
    64/1, 32/1, 16/1, 8/1, 4/1, 2/1, 1/1, 3/4, 1/2, 1/4, 1/16

  o BankStick support
    a 64k BS can store 127 patches, a 32k BS only 63 patches
    The BS size will be detected automatically during formatting
  o a "detune" parameter has been added to the CFG menu. It
    modifies the finetune of all oscillators
  o added GAE (gate always active) function - once set, the gate
    will never be released anymore. Instead, the voice volume has
    to be lowered externally or with a filter
  o added ABW (ADSR bug workaround) flag
    It adds an additional delay before the gate is activated.
    During this time, the ADSR registers are zeroed to ensure that
    the envelope has reached its final level before it will be
    triggered again.
    If you still notice ADSR hickups with a special configuration,
    just increase the ADSR delay in the OSC menu
    Note that the delay needs to be compensated from your sequencer.
    This feature is experimental and not suitable for live playing
  o the Env Ctrl button doesn't change the menu anymore
    so that the 5 rotary encoders of the ENV section can be used to
    change the currently visible menu items on a more confortable way
  o added V2A (Volume to AOUT) function which allows to forward
    the modulated volumes to 2 AOUT channels (assignments are defined in setup_*.asm)
    The internal volume is set to maximum if the V2A switch is enabled
  o added ARP oneshot mode
  o pitch (controlled by pitchbender) got a special parameter number: 80 dec, 0x50 hex
  o slave cloning function implemented
    press and hold the MENU button during boot to transfer the firmware 
    of the master to all slaves via the CAN interface
    This procedure takes ca. 30 seconds, some messages will be print
    on screen (if not, something is wrong with the MENU button detection -
    please inform me in this case)
  o preparation for multiple engines: separated SID_SE and CS_MENU_TABLE parts
  o started with multi engine
  o implemented ensemble functions, so that different channels and
    keyboard splitzones can be assigned to multi channel instruments
    an ensemble contains for each master/slave MBSID:
    - Bank/Pattern/Flags (like V2A, F2A)
    - Global Clock Generator settings
    - Filter calibration values (Min/Max) for left/right channel
    - the setup for 6 instruments (channel, splitzone, transpose)
  o the new ensemble menu page can be entered from the main menu:
    - press the leftmost select button below the LCD to enter ensemble menu
    - press any other select button below the LCD to enter the patch menu
  o up to 128 ensembles can be stored in a BankStick (only 32k allocated,
    so it doesn't matter if a 32k or 64k BankStick is used)
  o first beta release :)
  o there is now a S&H (Sample & Hold) operator available in the
    modmatrix which samples SRC1 whenever SRC2 changes from a negative
    to a positive value
  o an incoming patch or bank change request doesn't update the 
    the patch anymore if it was already selected before. This is to avoid
    "glitches" when a sequencer sends a program change shortly before
    a note is played.
  o the "Knobs" are sending CC values now when the CC function is
    activated (press SHIFT + Page Up/CC Button to toggle this mode)
    Other parameters are still not sending CCs over MIDI, as NRPNs
    are not implemented yet (low priority)
    The CC numbers are 1 for Knob #1 (Modulation wheel), and 16/17/18/19
    for Knob #2-#5 (GP values)
    In addition, Knob #P sends Pitchwheel Events in CC mode
  o support for analog inputs (J5:A0..A4)
    This feature has to be enabled in the setup_*.asm file by setting DEFAULT_J5_FUNCTION to 1
    Conversion results of the analog inputs are directly passed to the knob handler. 
    This generic approach has the advantage, that it is possible to control 5*2 parameters 
    within a specified Min/Max range, and that in addition the analog values are available
    as modulation source within the modulation matrix (K#1..K#5)

    The feature behaves differently on master and slaves:
    Master: analog inputs are forwarded to the selected SIDs - use this
            option as replacement for rotary encoders, or for adding
            analog control elements like pots/faders/joysticks to your CS
    Slave: analog inputs are only handled internally - use this option
           for modulation with analog signal generators
  o added "Notes Off" function to the SHIFT page (replaces Random
    function which has a separate menu page anyhow)
  o implemented bassline engine
  o support for AOUT_NG module
  o integrated support for ASID protocol, which has been originally
    developed for the SIDstation to replay .sid files.
    (see also http://www.midibox.org/forum/index.php?topic=2038.0)
    Only the master core (Device ID 00) will play SID tunes!
    Nice visual effect: the LED matrix of the CS shows three animated 
    meters whenever a gate flag of an oscillator is set.
    SID player mode is automatically enabled once an ASID stream is
    received. It can be exit by stopping the player on the PC, and 
    pressing the MENU button

    Unfortunately it turned out, that there is currently no SID player
    available which can replay .sid files properly via MIDI.

    - SIDplay (http://www.d.kth.se/~d93-alo/c64/spw/sidplayw.html)
      Perfect integration, but plays tunes too fast under WinXP.
      Works fine under Win95/Win98/WinME. Not tested under Vista
    - ASID (http://www.sidstation.com/sidsupport.php)
      Crashes under WinXP once the tune should be played
    - ASID XP (http://www.sidstation.com/files/asid_xp_1.0.zip)
      Tunes played correctly, but the MIDI stream is corrupted at 
      the very beginning when the player is started. Accordingly the
      sounds are not properly initialized.

    Workaround: start a tune with SIDplay (for proper sound
    initialisation), thereafter play it with ASID XP
  o resonance now editable with 8bit resolution (only applicable for F2A option)
  o implemented global BPM generator, which replaces the global clock divider
    for more consistent clock handling
    Now it doesn't make a difference anymore, if MBSID receives a 
    clock at a certain BPM, or if it generates it internally
  o support for sustain CC#64 (if CC value >= 0x40, notes will be
    held, with CC value < 0x40, notes will be released)
    Currently only supported for lead engine!
  o drum engine implemented
  o meter mode now also supported for multi/bassline/drum engine
  o superpoly function implemented for lead engine (experimental!)
  o various improvements for drum sequence editing:
    - cursor now controlled with encoder
    - the "<" function has been replaced by a rotate function, which
      allows you to scroll the pattern left/right
    - the ">" function has been replaced by a direct shortcut to
      the DRM menu page - the instrument number will be set 
      automatically according to the selected track
    - the mod target buttons (named with E1/E2/L1/...L6) now 
      change to the track editor, and select the appr. track (1-8)
  o implemented MIDI Clock Master/Slave Auto Detection
  o bassline/drum sequences now stopped when a MIDI Clock Stop
    event has been received
  o bassline/drum sequences now started when a MIDI Clock Start or
    Continue event has been received
  o improved "play button" function (e.g. only selected instruments
    played, selected drum is triggered, etc...)
  o support for "Sync" button (it just jumps into the ENS->CLK
    menu for Master/Slave/Auto mode and BPM selection)
  o support for full parameter access via NRPNs
    see mbsidv2_parameter_chart.txt for details
  o possibilities to select a patch:
      - moving datawheel in main screen (as before)
      - using Page Up/Down button in main screen and patch main menu
      - selecting bank and patch in the ENS->SID menu
  o possibilities to select an ensemble:
      - pressing MENU + moving datawheel in main screen
      - using MENU + Page Up/Down button in main screen
      - using Page Up/Down button in ENS menu
  o ensemble can now be initialised with preset (-> go into ENS
    menu, press SHIFT button, select "Ini.Ens" option)
    Note that Patch and Bank settings won't be touched by
    this initialisation!
  o there is now a new EXT page within the ensemble menu which
    contains following options:
       - F2A (Filter-to-Analog): was previously located in SID menu
       - V2A (Volume-to-Analog): was previously located in SID menu
       - Iv1..Iv8: inversion of output voltage at channel #1..#8
  o added optional FIP option (Filter Interpolation) which smoothes
    CutOff changes. It is especially useful when CutOff is changed
    via CC (-> low resolution) to reduce the steppyness.
    The option is not useful when the CutOff parameter is modulated from
    a fast LFO or envelope (on the other hand: it produces interesting
    effects in such cases ;-)

--------------------------------------------------------------------------------
--------------------------------------------------------------------------------
--------------------------------------------------------------------------------

MEMO:
  - in Bassline mode, CCs could control individual knob parameters for
    left/right channel by using the "current" assignment, and selecting
    the instrument (L-, -R or LR) via different sets of CC

  - a solution has to be found for bassline mode, how values changed
    via knobs should be properly forwarded to the edit patch storage
    for consistent value sets
    As this method has advantages and disadvantages (e.g. destructive
    changes in the edit patch are mostly NOT wanted!), maybe a soft-option
    could be provided (but I'm sure, that most people would disable it
    quickly once they noticed the disadvantages)

  - There is currently a "Notes Off" in the Shift menu which allows to
    turn off all notes of the selected SID(s)
    For more comfort, it could make sense to send this command too all
    SIDs independent from the SID selection
    In addition, a "Note On" (Play) command could also be placed into
    the Shift menu - but where? (maybe as replacement for Init Patch,
    as a patch can also be initialized by changing the engine)

  - drum engine mode: additional parameter for WT table offset?

  - individual copy/paste/clr function for drum instruments?

  - individual save function for instruments (for all engines)

  - selection of bank/patch within same screen in ENS->SID->Bnk/Pat page

  - if multiple SIDs with different engines are connected, the
    performed CS modifications (button/encoder turns) can result into
    a big mess. A fix isn't so easy (easiest but inconsistent solution: the
    master has to remember the engines of SID1..4 in order to decide,
    if a parameter is allowed for beeing sent)

  - theoretically it could be possible to modulate 8 of 256 sound
    parameters (which are normaly only accessible via knobs, WT or NRPN)
    from the modulation pathes (e.g. envelope or LFO source) by providing
    a special EXT -> Par (AOUT Value -> Sound Parameter) routing.
    Since 8 EXT values are available with 12bit resolution, this should
    be sufficient for most cases.
    The AOUT option wouldn't be available in such a mode...

  - the external switches could be optionally triggered by notes, or
    maybe better: reflect the gate of ENV1 and/or ENV2 which is used to switch
    between attack/decay/sustain and release phase
    This would be a quite useful function for external ADSR generators
    Problem: which possibilities are really required, how should it
    behave for the different engines, how should it be configured? Within ensemble?

  - a switch which disables the menu jumping when an encoder has been moved
    has been requested from multiple users meanwhile

  - a switch which swaps the encoder speed selection: slow by default, fast
    if SHIFT button pressed

  - add Display the state of OSC1 arp on a custom LED
    (pendant to CS_MENU_BUTTON_Arp button function)

  - The WT "key" control feature could alternatively start a (short) sequence
    instead of only selecting a single WT position.
    This would allow to embedd multiple WT sounds (e.g. drums) into a patch,
    and to select them with the note number (especially nice for multi patches)

-------------------------------------------------------------------------
Wilba wrote:
Starting with a completely init ensemble, init patch... turn on arp for osc 1, sort on, 

dir up, range 1, play C3 E3 G3 => loop { C3 E3 G3 }   (good)
dir down, range 1, play C3 E3 G3 => loop { G3 E3 C3 }   (good)

dir up, range 2, play C3 E3 G3 => loop { C3 E3 G3 C4 E4 G4 }   (good)
dir down, range 2, play C3 E3 G3 => loop { C3 G3 E3 C4 G4 E4 }   (wtf? i expected loop { G4 E4 C4 G3 E3 C3 } )

This continues in a strange way if you add more notes:
dir down, range 2, play C3 E3 G3 A3 => loop { C3 A3 G3 E3 C4 A4 G4 E4 }   (wtf?)

anyway... I was expecting that the range parameter is always positive octaves, i.e. you will get the notes repeated with a +12 semitone transpose, and if you happen to play notes more spaced than 12 semitones then I wouldn't expect it to do anything fancy to avoid a sequence which is not an ordered "note number"
i.e. dir up, range 2, play C3 C4 C5 => loop ( C3 C4 C5 C4 C5 C6 ) no problem for me ;-)

but when using down direction and range > 1, shouldn't it be the exact inverse of what you would get for up direction and range > 1?
-------------------------------------------------------------------------

  - additional LFO MIDI sync values: 1/4T 1/8T 1/16T... and 1/2P 1/4P, ...

-------------------------------------------------------------------------
Florian wrote:
when using bassline seq, if i sequence a c, it will run the first pattern ok. 
So on a 16 step pattern on the md, i put a c on the first step, and a 4/4beat.
But if i say to the md roll on now on the 2 first step by changing the pattern lenght, the bassline seq continue is run even if the c is retrigerred which could be a cool thing, but can too do some desync if in fact i don't tell the md to re-go to 16 step perfectly in sync. So is there a way to force the sid seq to began at the beginnig of the pattern each time the c is trigerred???
-------------------------------------------------------------------------

Send MIDI Clock

-------------------------------------------------------------------------

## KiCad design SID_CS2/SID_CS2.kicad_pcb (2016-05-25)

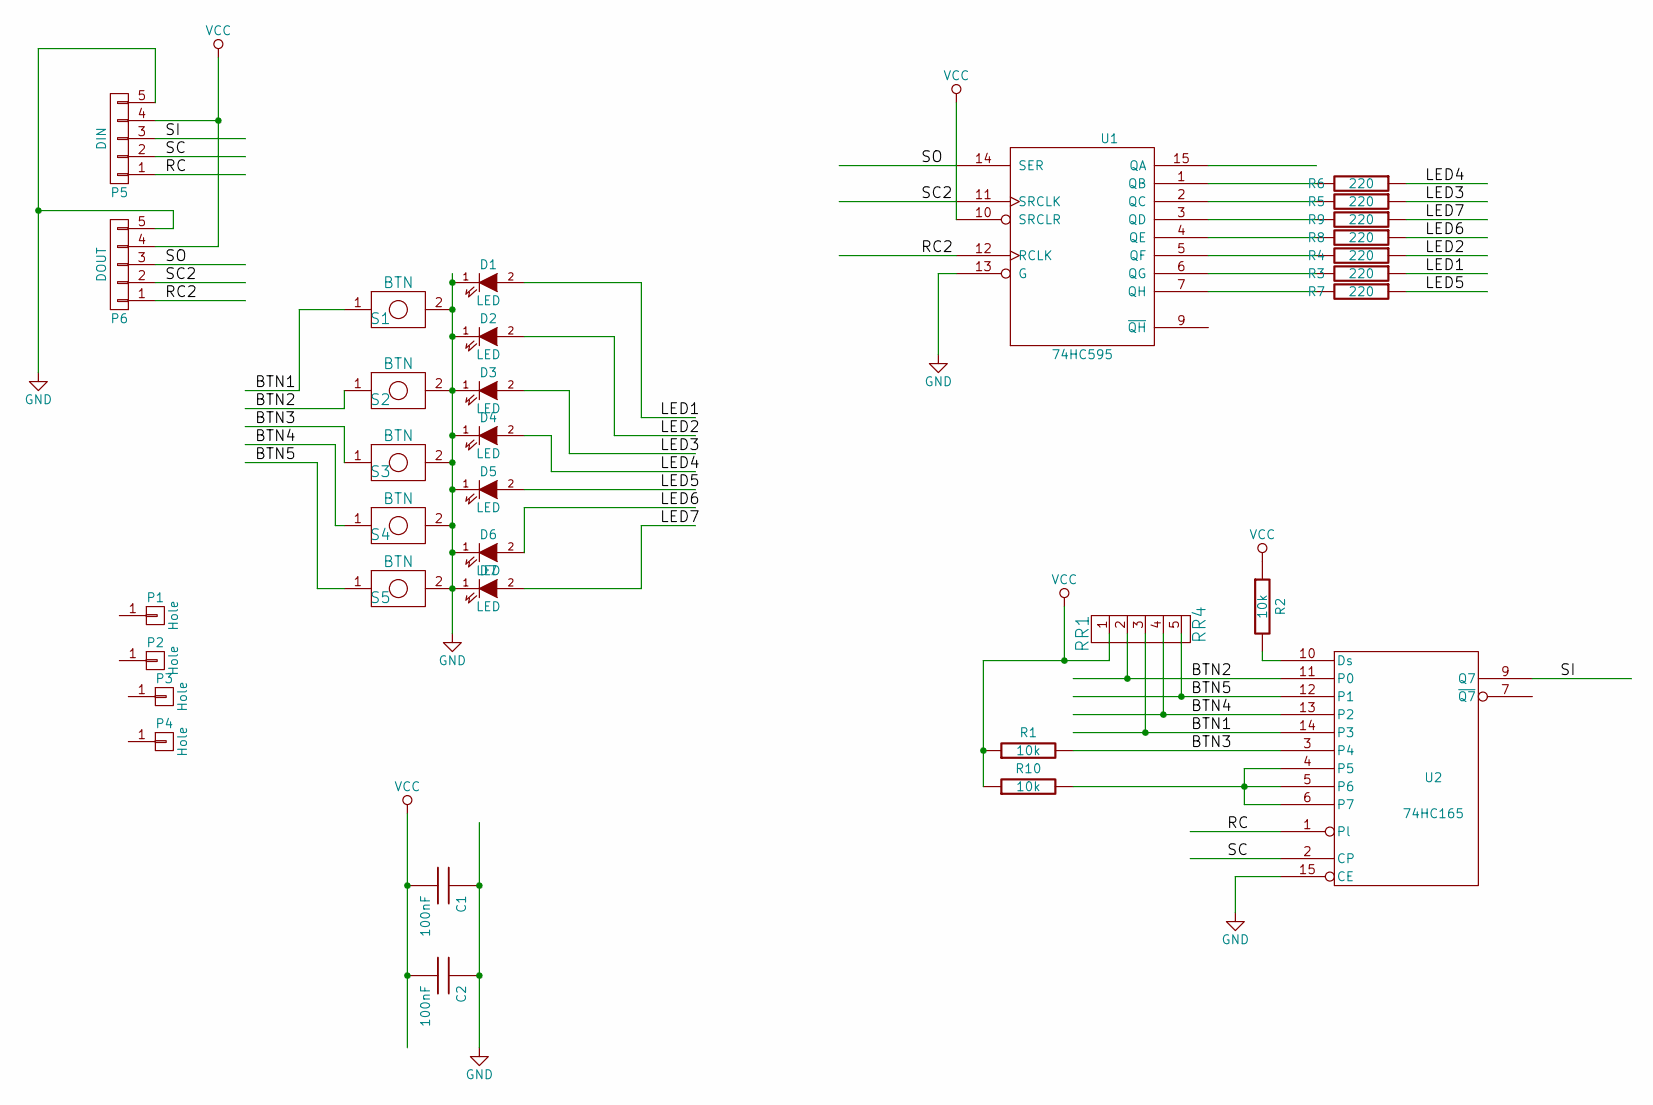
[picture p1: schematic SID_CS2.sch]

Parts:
C1, C2: 100nF; C_Disc_D3_P2.5
D1, D2, D3, D4, D5, D6, D7: LED; FMLed2
P1, P2, P3, P4: Hole; MountingHole_3.2mm_M3
P5: DIN; Pin_Header_Straight_1x05
P6: DOUT; Pin_Header_Straight_1x05
R1, R2, R10: 10k; Resistor_Horizontal_RM7mm
R3, R4, R5, R6, R7, R8, R9: 220; Resistor_Horizontal_RM7mm
RR1: RR4; Pin_Header_Straight_1x05
S1, S2, S3, S4, S5: BTN; FMButton2
U1: 74HC595; DIP-16_W7.62mm
U2: 74HC165; DIP-16_W7.62mm

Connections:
/BTN1: RR1.3, S1.1, U2.14 (P3)
/BTN2: RR1.2, S2.1, U2.11 (P0)
/BTN3: R1.2, S3.1, U2.3 (P4)
/BTN4: RR1.4, S4.1, U2.13 (P2)
/BTN5: RR1.5, S5.1, U2.12 (P1)
/LED1: D1.2 (A), R3.1
/LED2: D2.2 (A), R4.1
/LED3: D3.2 (A), R5.1
/LED4: D4.2 (A), R6.1
/LED5: D5.2 (A), R7.1
/LED6: D6.2 (A), R8.1
/LED7: D7.2 (A), R9.1
/RC: P5.1, U2.1 (Pl)
/RC2: P6.1, U1.12 (RCLK)
/SC: P5.2, U2.2 (CP)
/SC2: P6.2, U1.11 (SRCLK)
/SI: P5.3, U2.9 (Q7)
/SO: P6.3, U1.14 (SER)
GND: C1.1, C2.1, D1.1 (K), D2.1 (K), D3.1 (K), D4.1 (K), D5.1 (K), D6.1 (K), D7.1 (K), P5.5, P6.5, S1.2, S2.2, S3.2, S4.2, S5.2, U1.8 (GND), U1.13 (G), U2.8 (GND), U2.15 (CE)
unnamed: R2.2, U2.10 (Ds)
unnamed: R3.2, U1.6 (QG)
unnamed: R4.2, U1.5 (QF)
unnamed: R5.2, U1.2 (QC)
unnamed: R6.2, U1.1 (QB)
unnamed: R7.2, U1.7 (QH)
unnamed: R8.2, U1.4 (QE)
unnamed: R9.2, U1.3 (QD)
unnamed: R10.2, U2.4 (P5), U2.5 (P6), U2.6 (P7)
VCC: C1.2, C2.2, P5.4, P6.4, R1.1, R2.1, R10.1, RR1.1, U1.10 (SRCLR), U1.16 (VCC), U2.16 (VCC)

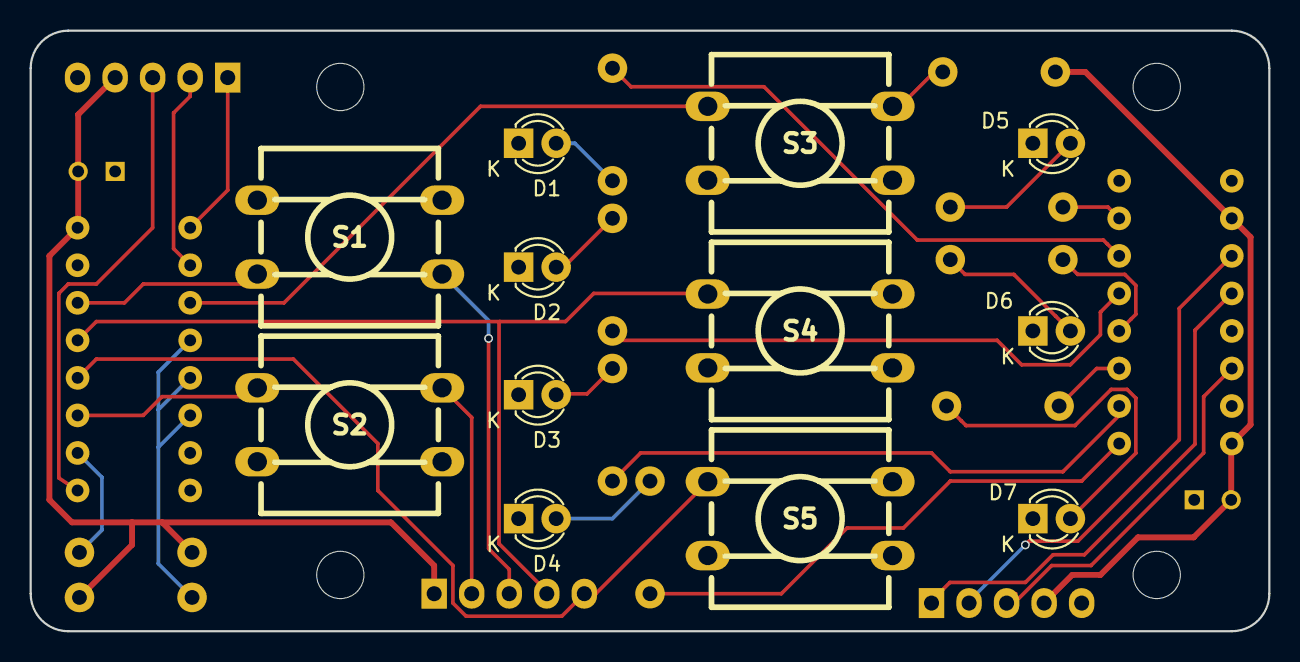
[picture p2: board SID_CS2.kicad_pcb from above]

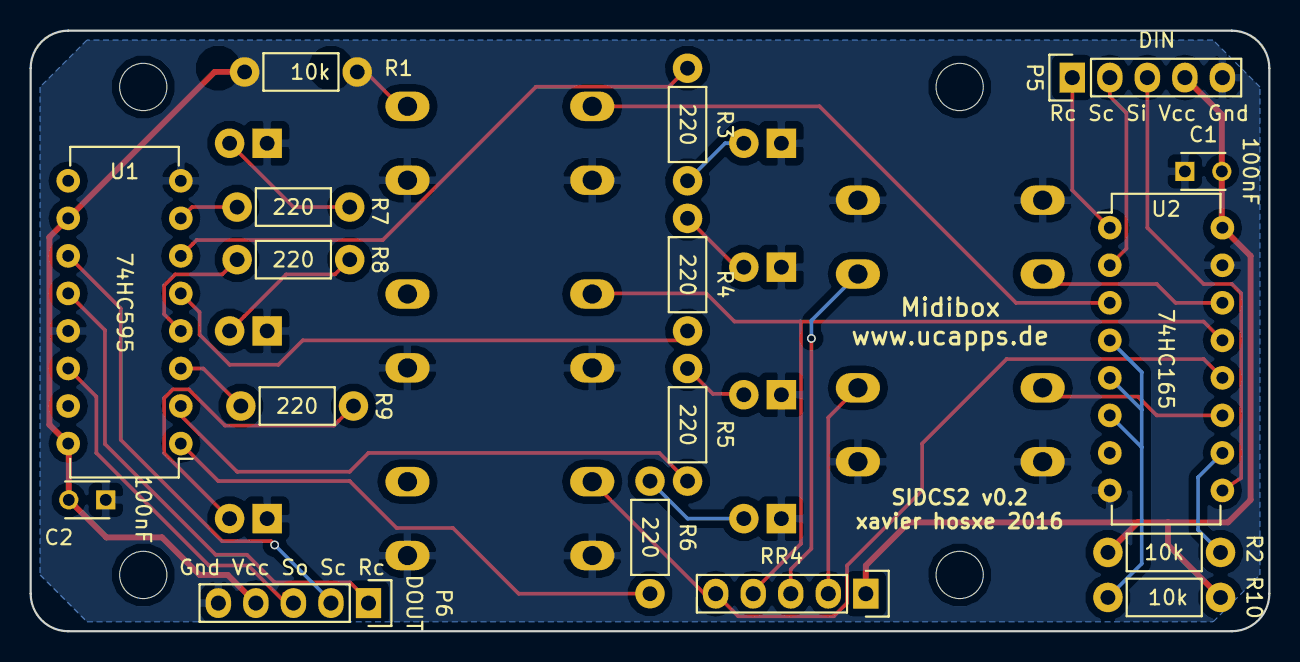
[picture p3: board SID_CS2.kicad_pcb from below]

Board: 2 copper layers, 83.8 x 40.6 mm, 33 parts (17 on the bottom side), 29 nets.

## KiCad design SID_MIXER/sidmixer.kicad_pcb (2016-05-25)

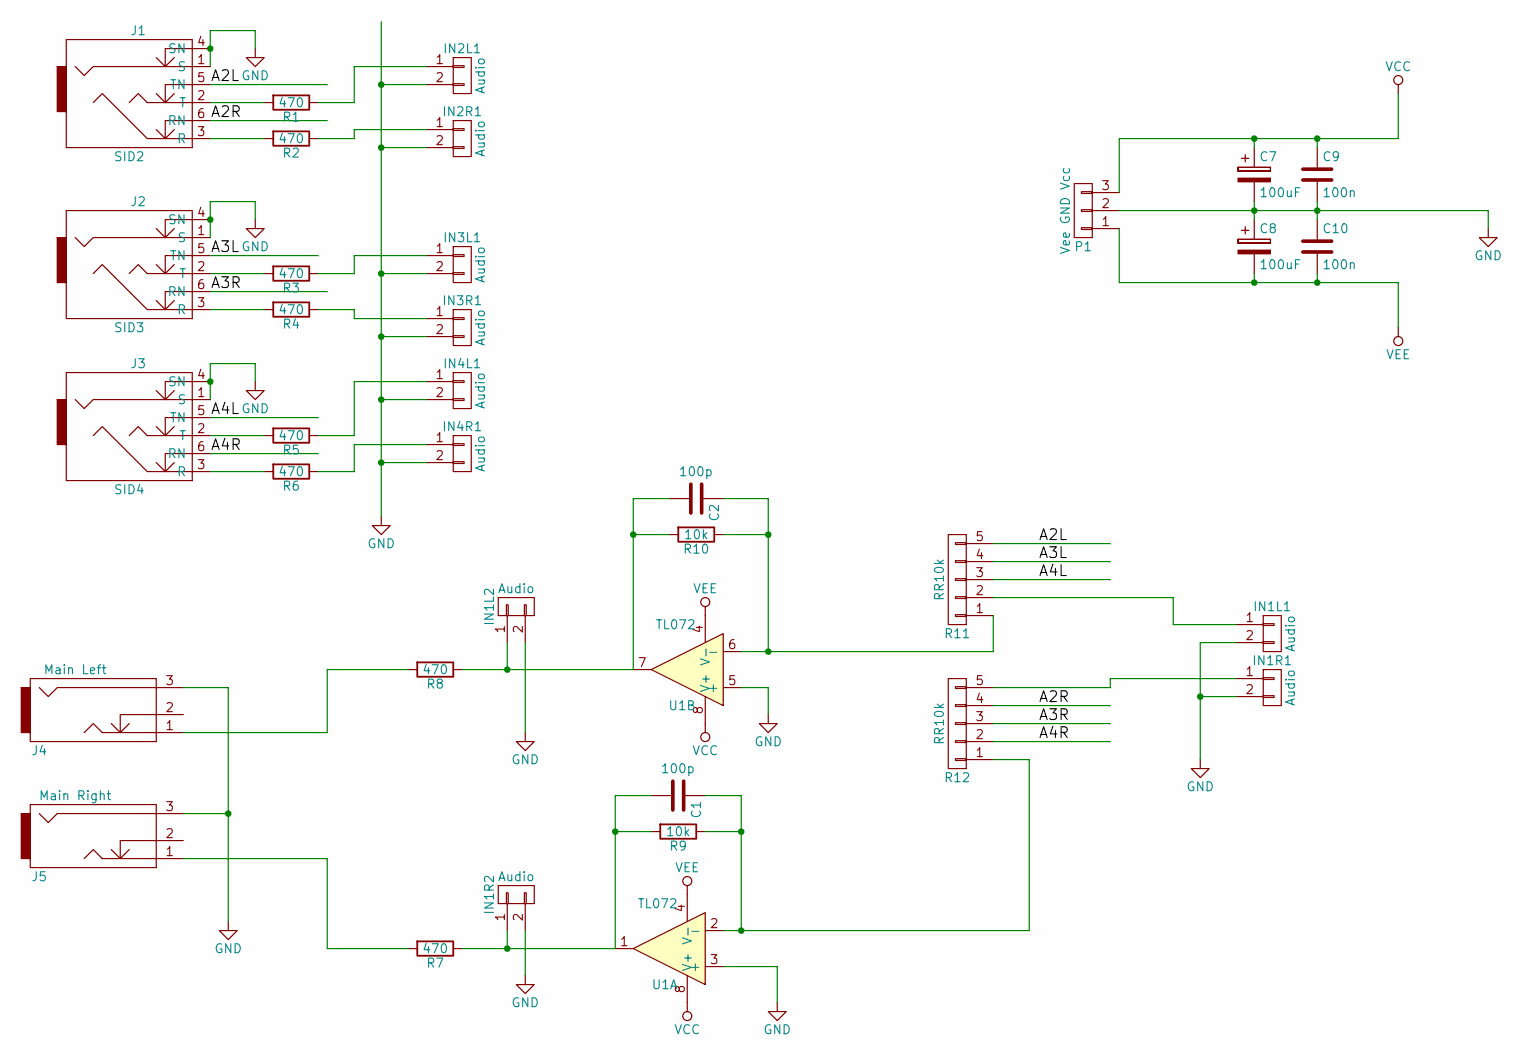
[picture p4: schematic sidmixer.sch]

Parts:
C1, C2: 100p; C_Disc_D3_P2.5
C7, C8: 100uF; C_Radial_D6.3_L11.2_P2.5
C9, C10: 100n; C_Disc_D3_P2.5
IN1L1, IN1L2, IN1R1, IN1R2, IN2L1, IN2R1, IN3L1, IN3R1, IN4L1, IN4R1: Audio; Pin_Header_Straight_1x02
J1: SID2; NRJ6HF
J2: SID3; NRJ6HF
J3: SID4; NRJ6HF
J4: Main Left; NRJ4HF
J5: Main Right; NRJ4HF
P1: Vee GND Vcc; Pin_Header_Straight_1x03
R1, R2, R3, R4, R5, R6, R7, R8: 470; Resistor_Horizontal_RM7mm
R9, R10: 10k; Resistor_Horizontal_RM7mm
R11, R12: RR10k; FMRR
U1: TL072; DIP-8_W7.62mm

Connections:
/A2L: J1.5 (TN), R11.5
/A2R: J1.6 (RN), R12.4
/A3L: J2.5 (TN), R11.4
/A3R: J2.6 (RN), R12.3
/A4L: J3.5 (TN), R11.3
/A4R: J3.6 (RN), R12.2
GND: C7.2, C8.1, C9.2, C10.1, IN1L1.2, IN1L2.2, IN1R1.2, IN1R2.2, IN2L1.2, IN2R1.2, IN3L1.2, IN3R1.2, IN4L1.2, IN4R1.2, J1.1 (S), J1.4 (SN), J2.1 (S), J2.4 (SN), J3.1 (S), J3.4 (SN), J4.3, J5.3, P1.2, U1.3 (+), U1.5 (+)
unnamed: C1.1, R9.1, R12.1, U1.2 (-)
unnamed: C1.2, IN1R2.1, R7.1, R9.2, U1.1
unnamed: C2.1, R10.1, R11.1, U1.6 (-)
unnamed: C2.2, IN1L2.1, R8.1, R10.2, U1.7
unnamed: IN1L1.1, R11.2
unnamed: IN1R1.1, R12.5
unnamed: IN2L1.1, R1.1
unnamed: IN2R1.1, R2.1
unnamed: IN3L1.1, R3.1
unnamed: IN3R1.1, R4.1
unnamed: IN4L1.1, R5.1
unnamed: IN4R1.1, R6.1
unnamed: J1.2 (T), R1.2
unnamed: J1.3 (R), R2.2
unnamed: J2.2 (T), R3.2
unnamed: J2.3 (R), R4.2
unnamed: J3.2 (T), R5.2
unnamed: J3.3 (R), R6.2
unnamed: J4.1, R8.2
unnamed: J5.1, R7.2
VCC: C7.1, C9.1, P1.3, U1.8 (V+)
VEE: C8.2, C10.2, P1.1, U1.4 (V-)

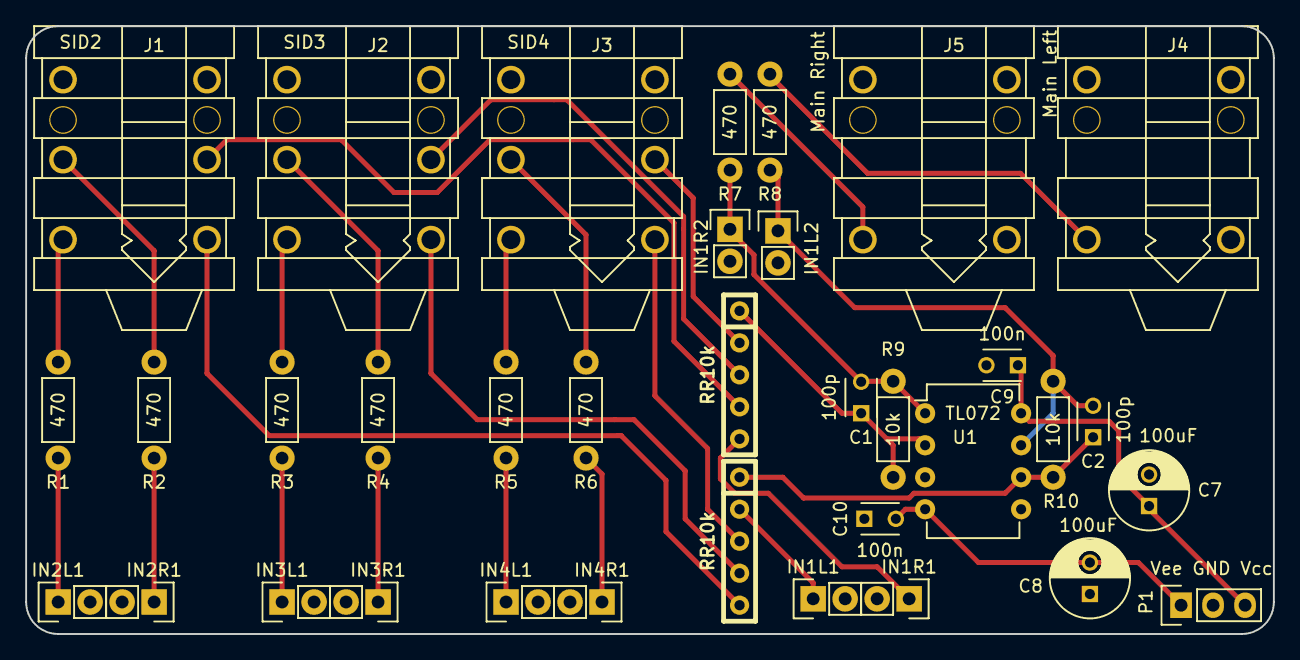
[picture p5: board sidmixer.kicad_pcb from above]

Board: 2 copper layers, 99.1 x 48.3 mm, 35 parts (0 on the bottom side), 29 nets.

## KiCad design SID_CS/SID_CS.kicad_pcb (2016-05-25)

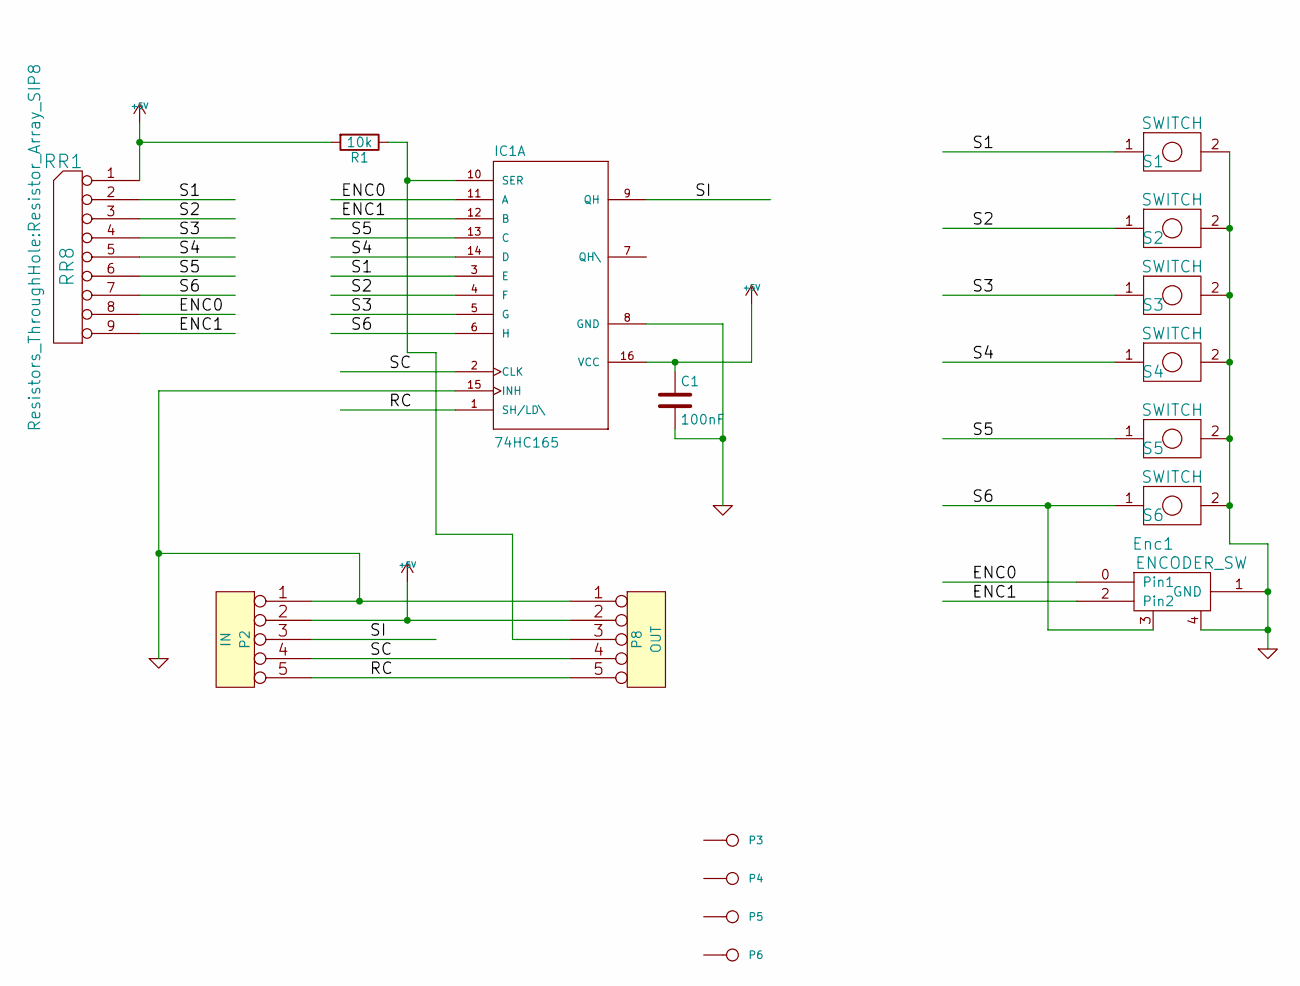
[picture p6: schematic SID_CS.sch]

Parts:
C1: 100nF; C_Disc_D3_P2.5
Enc1: ENCODER_SW; FMEncoderWithSwitch2
IC1: 74HC165; DIP-16_W7.62mm_LongPads
P2: IN; Pin_Header_Straight_1x05
P3, P4, P5, P6: CONN_1; MountingHole_3.2mm_M3
P8: OUT; Pin_Header_Straight_1x05
R1: 10k; Resistor_Horizontal_RM7mm
RR1: RR8; Resistor_Array_SIP8
S1, S2, S3, S4, S5, S6: SWITCH; FMButton2

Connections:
+5V: C1.1, IC1.16 (VCC), P2.2, P8.2, R1.2, RR1.1 (COM)
/ENC0: Enc1.0 (Pin1), IC1.11 (A), RR1.8
/ENC1: Enc1.2 (Pin2), IC1.12 (B), RR1.9
/RC: IC1.1 (SH/LD\), P2.5, P8.5
/S1: IC1.3 (E), RR1.2, S1.1
/S2: IC1.4 (F), RR1.3, S2.1
/S3: IC1.5 (G), RR1.4, S3.1
/S4: IC1.14 (D), RR1.5, S4.1
/S5: IC1.13 (C), RR1.6, S5.1
/S6: Enc1.3, IC1.6 (H), RR1.7, S6.1
/SC: IC1.2 (CLK), P2.4, P8.4
/SI: IC1.9 (QH), P2.3
GND: C1.2, Enc1.1 (GND), Enc1.4, IC1.8 (GND), IC1.15 (INH), P2.1, P8.1, S1.2, S2.2, S3.2, S4.2, S5.2, S6.2
unnamed: IC1.10 (SER), P8.3, R1.1

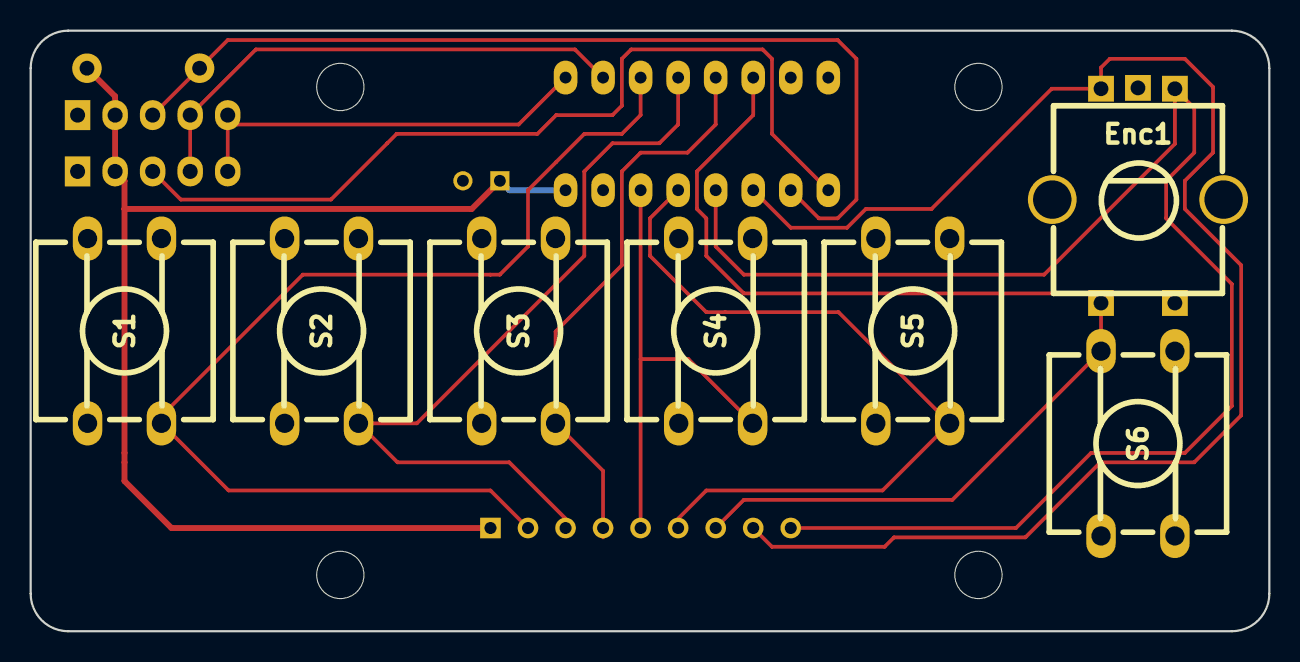
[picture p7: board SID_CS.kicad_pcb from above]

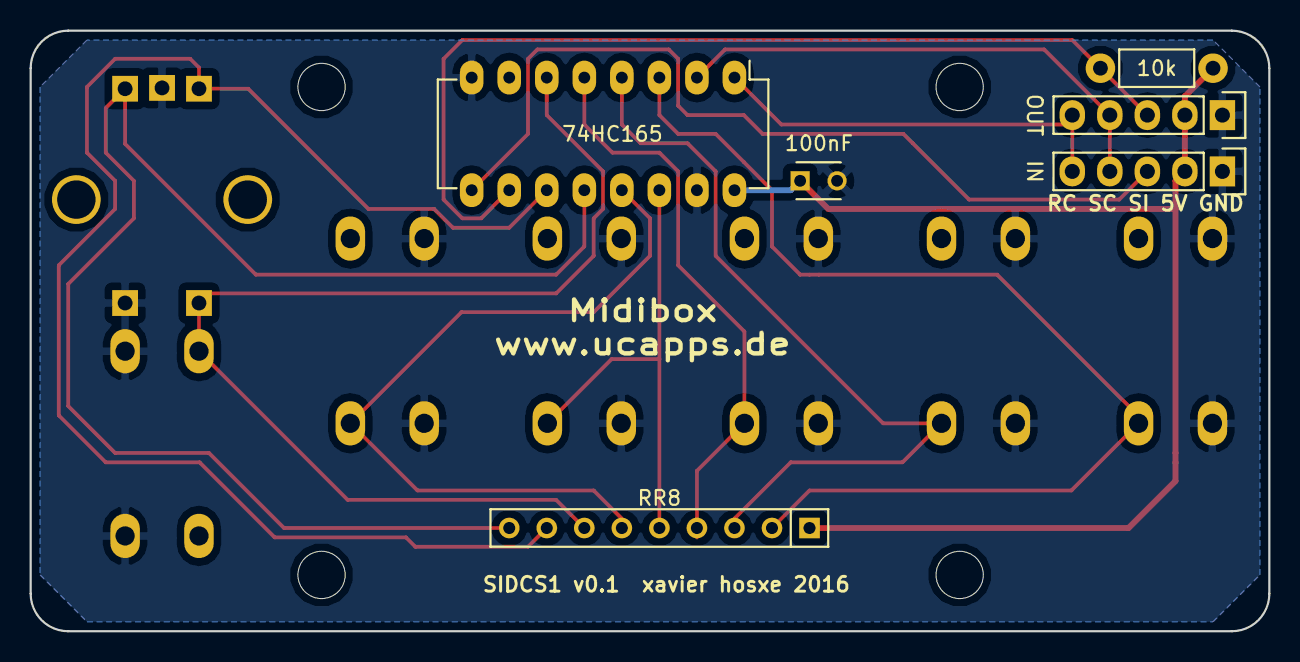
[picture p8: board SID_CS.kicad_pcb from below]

Board: 2 copper layers, 83.8 x 40.6 mm, 17 parts (6 on the bottom side), 14 nets.

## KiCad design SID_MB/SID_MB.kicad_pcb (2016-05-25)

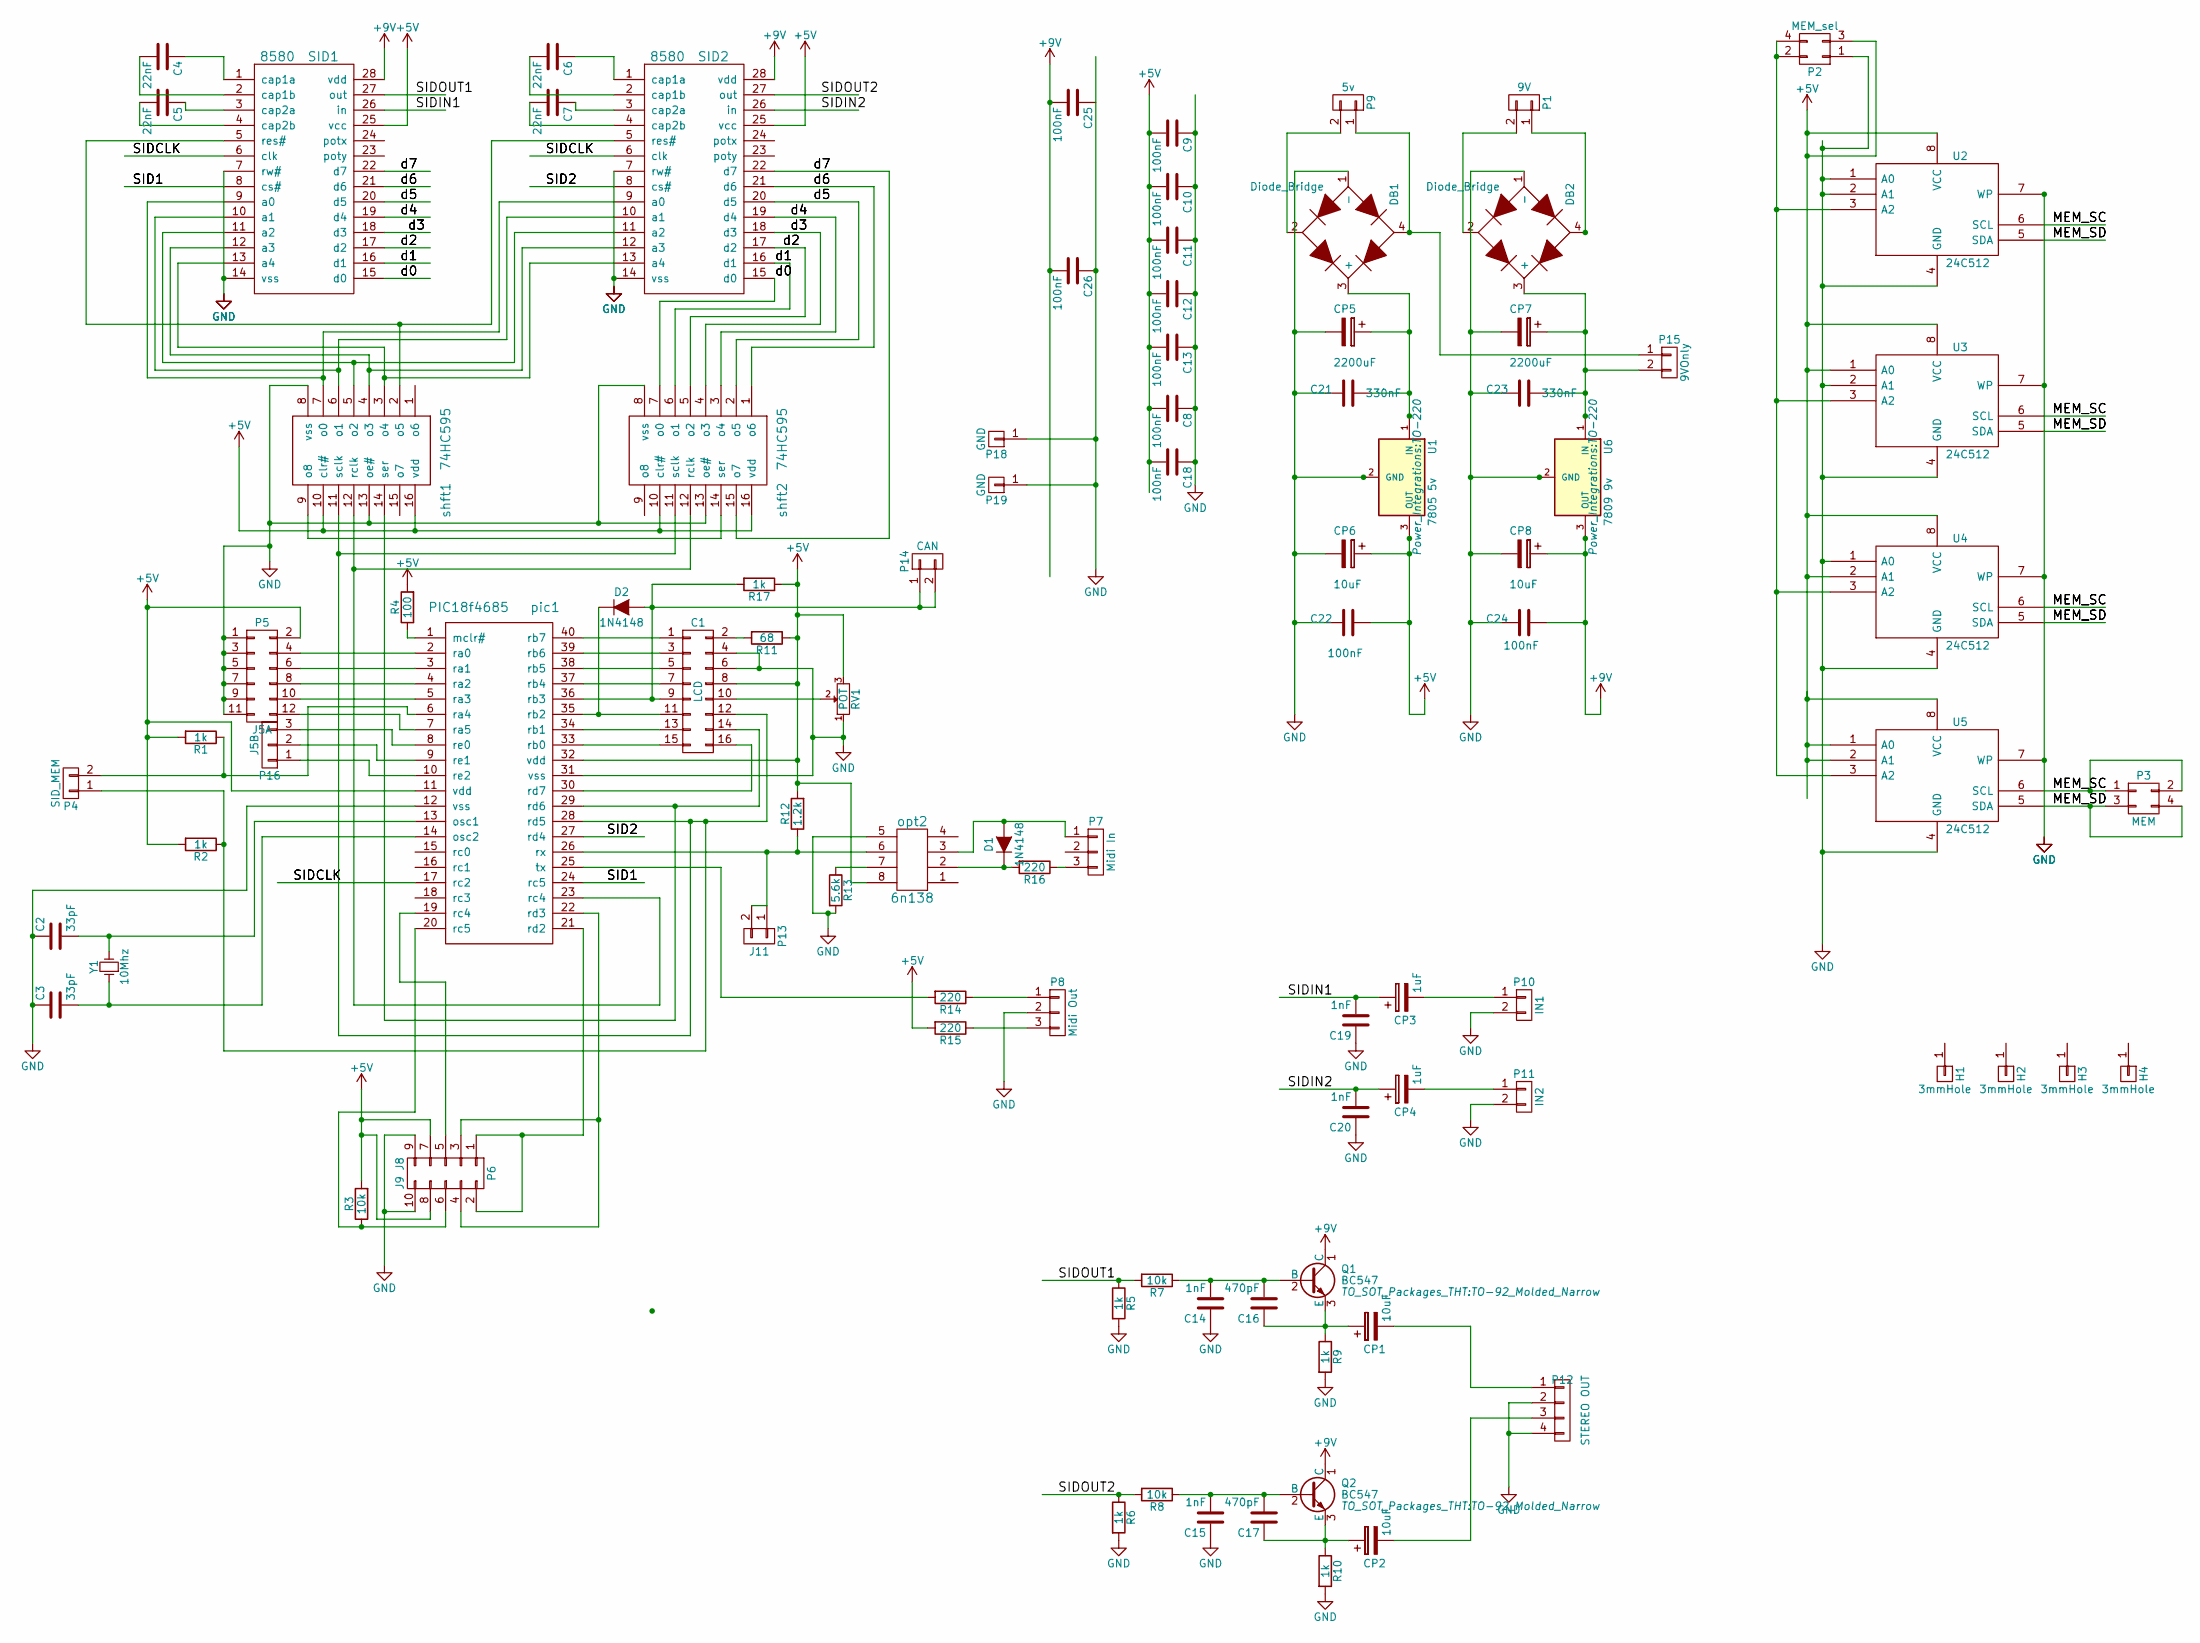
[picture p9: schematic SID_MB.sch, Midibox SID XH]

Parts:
C1: LCD; Pin_Header_Straight_2x08
C2, C3: 33pF; C_Rect_L4_W2.5_P2.5
C4, C5, C6, C7: 22nF; C_Rect_L4_W2.5_P2.5
C8, C9, C10, C11, C12, C13, C18, C22, C24, C25, C26: 100nF; C_Rect_L4_W2.5_P2.5
C14, C15, C19, C20: 1nF; C_Rect_L4_W2.5_P2.5
C16, C17: 470pF; C_Rect_L4_W2.5_P2.5
C21, C23: 330nF; C_Rect_L4_W2.5_P2.5
CP1, CP2, CP6, CP8: 10uF; C_Radial_D5_L6_P2.5
CP3, CP4: 1uF; C_Radial_D5_L6_P2.5
CP5, CP7: 2200uF; C_Radial_D12.5_L25_P5
D1, D2: 1N4148; Diode_DO-35_SOD27_Horizontal_RM10
DB1, DB2: Diode_Bridge; Bridge-rond
H1, H2, H3, H4: 3mmHole; MountingHole_3.2mm_M3
P1: 9V; bornier2
P2: MEM_sel; Pin_Header_Straight_2x02
P3: MEM; Pin_Header_Straight_2x02
P4: SID_MEM; Pin_Header_Straight_1x02
P5: J5A; Pin_Header_Straight_2x06
P6: J9 J8; Pin_Header_Straight_2x05
P7: Midi In; Pin_Header_Straight_1x03
P8: Midi Out; Pin_Header_Straight_1x03
P9: 5v; bornier2
P10: IN1; Pin_Header_Straight_1x02
P11: IN2; Pin_Header_Straight_1x02
P12: STEREO OUT; Pin_Header_Straight_1x04
P13: J11; Pin_Header_Straight_1x02
P14: CAN; Pin_Header_Straight_1x02
P15: 9VOnly; Pin_Header_Straight_1x02
P16: J5B; Pin_Header_Straight_1x03
P18, P19: GND; Pin_Header_Straight_1x01
Q1, Q2: BC547; TO-92_Molded_Narrow
R1, R2, R5, R6, R9, R10, R17: 1k; Resistor_Horizontal_RM7mm
R3, R7, R8: 10k; Resistor_Horizontal_RM7mm
R4: 100; Resistor_Horizontal_RM7mm
R11: 68; Resistor_Horizontal_RM7mm
R12: 1.2k; Resistor_Horizontal_RM7mm
R13: 5.6k; Resistor_Horizontal_RM7mm
R14, R15, R16: 220; Resistor_Horizontal_RM7mm
RV1: POT; FMRV
SID1, SID2: 8580; DIP-28_W15.24mm_LongPads
U1: 7805 5v; TO-220
U2, U3, U4, U5: 24C512; DIP-8_W7.62mm
U6: 7809 9v; TO-220
Y1: 10Mhz; Crystal_HC49-U_Vertical
opt2: 6n138; DIP-8_W7.62mm
pic1: PIC18f4685; DIP-40_W15.24mm
shft1, shft2: 74HC595; DIP-16_W7.62mm_LongPads

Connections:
+5V: C1.8, C8.2, C9.2, C10.2, C11.2, C12.2, C13.2, C18.2, C22.2, CP6.1, P2.3, P5.2, P6.7, P6.8, R1.2, R2.2, R3.2, R4.2, R11.1, R12.2, R15.2, R17.1, RV1.3, SID1.25 (vcc), SID2.25 (vcc), U1.3 (OUT), U2.8 (VCC), U3.1 (A0), U3.8 (VCC), U4.2 (A1), U4.8 (VCC), U5.1 (A0), U5.2 (A1), U5.8 (VCC), opt2.8, pic1.11 (vdd), pic1.32 (vdd), shft1.10 (clr#), shft1.16 (vdd), shft2.10 (clr#), shft2.16 (vdd)
+9V: C24.2, C25.2, C26.2, CP8.1, Q1.1 (C), Q2.1 (C), SID1.28 (vdd), SID2.28 (vdd), U6.3 (OUT)
/MEM_SC: P3.1, P3.2, U2.6 (SCL), U3.6 (SCL), U4.6 (SCL), U5.6 (SCL)
/MEM_SD: P3.3, P3.4, U2.5 (SDA), U3.5 (SDA), U4.5 (SDA), U5.5 (SDA)
/SID1: SID1.8 (cs#), pic1.24 (rc5)
/SID2: SID2.8 (cs#), pic1.27 (rd4)
/SIDCLK: SID1.6 (clk), SID2.6 (clk), pic1.17 (rc2)
/SIDIN1: C19.2, CP3.1, SID1.26 (in)
/SIDIN2: C20.2, CP4.1, SID2.26 (in)
/SIDOUT1: R5.1, R7.2, SID1.27 (out)
/SIDOUT2: R6.1, R8.2, SID2.27 (out)
/d0: SID1.15 (d0), SID2.15 (d0), shft2.7 (o0)
/d1: SID1.16 (d1), SID2.16 (d1), shft2.6 (o1)
/d2: SID1.17 (d2), SID2.17 (d2), shft2.5 (o2)
/d3: SID1.18 (d3), SID2.18 (d3), shft2.4 (o3)
/d4: SID1.19 (d4), SID2.19 (d4), shft2.3 (o4)
/d5: SID1.20 (d5), SID2.20 (d5), shft2.2 (o5)
/d6: SID1.21 (d6), SID2.21 (d6), shft2.1 (o6)
/d7: SID1.22 (d7), SID2.22 (d7), shft2.15 (o7)
GND: C1.4, C1.6, C2.1, C3.1, C8.1, C9.1, C10.1, C11.1, C12.1, C13.1, C14.1, C15.1, C18.1, C19.1, C20.1, C21.1, C22.1, C23.1, C24.1, C26.1, CP5.2, CP6.2, CP7.2, CP8.2, DB1.1 (-), DB2.1 (-), P2.1, P5.1, P5.3, P5.5, P5.7, P5.9, P5.11, P6.9, P6.10, P8.2, P10.2, P11.2, P12.2, P12.4, P18.1, P19.1, R5.2, R6.2, R9.2, R10.2, R13.2, RV1.1, SID1.7 (rw#), SID1.14 (vss), SID2.7 (rw#), SID2.14 (vss), U1.2 (GND), U2.1 (A0), U2.2 (A1), U2.4 (GND), U2.7 (WP), U3.2 (A1), U3.4 (GND), U3.7 (WP), U4.1 (A0), U4.4 (GND), U4.7 (WP), U5.4 (GND), U5.7 (WP), U6.2 (GND), opt2.5, pic1.12 (vss), pic1.31 (vss), shft1.8 (vss), shft1.13 (oe#), shft2.8 (vss), shft2.13 (oe#)
unnamed: C1.1, pic1.40 (rb7)
unnamed: C1.2, R11.2
unnamed: C1.3, pic1.39 (rb6)
unnamed: C1.5, pic1.38 (rb5)
unnamed: C1.7, pic1.37 (rb4)
unnamed: C1.9, D2.2 (A), P14.1, P14.2, R17.2, pic1.36 (rb3)
unnamed: C1.10, RV1.2
unnamed: C1.11, D2.1 (K), pic1.35 (rb2)
unnamed: C1.12, P4.1, R2.1, pic1.28 (rd5), shft1.11 (sclk), shft2.11 (sclk)
unnamed: C1.13, pic1.34 (rb1)
unnamed: C1.14, pic1.29 (rd6), shft1.14 (ser)
unnamed: C1.15, pic1.33 (rb0)
unnamed: C1.16, pic1.30 (rd7)
unnamed: C2.2, Y1.2, pic1.13 (osc1)
unnamed: C3.2, Y1.1, pic1.14 (osc2)
unnamed: C4.1, SID1.1 (cap1a)
unnamed: C4.2, SID1.2 (cap1b)
unnamed: C5.1, SID1.3 (cap2a)
unnamed: C5.2, SID1.4 (cap2b)
unnamed: C6.1, SID2.1 (cap1a)
unnamed: C6.2, SID2.2 (cap1b)
unnamed: C7.1, SID2.3 (cap2a)
unnamed: C7.2, SID2.4 (cap2b)
unnamed: C14.2, C16.2, Q1.2 (B), R7.1
unnamed: C15.2, C17.2, Q2.2 (B), R8.1
unnamed: C16.1, CP1.1, Q1.3 (E), R9.1
unnamed: C17.1, CP2.1, Q2.3 (E), R10.1
unnamed: C21.2, CP5.1, DB1.3 (+), U1.1 (IN)
unnamed: C23.2, CP7.1, DB2.3 (+), P15.2, U6.1 (IN)
unnamed: CP1.2, P12.1
unnamed: CP2.2, P12.3
unnamed: CP3.2, P10.1
unnamed: CP4.2, P11.1
unnamed: D1.1 (K), R16.2, opt2.2
unnamed: D1.2 (A), P7.1, opt2.3
unnamed: DB1.2, P9.2
unnamed: DB1.4, P9.1, P15.1
unnamed: DB2.2, P1.2
unnamed: DB2.4, P1.1
unnamed: P2.2, P2.4, U2.3 (A2), U3.3 (A2), U4.3 (A2), U5.3 (A2)
unnamed: P4.2, R1.1, pic1.6 (ra4)
unnamed: P5.4, pic1.2 (ra0)
unnamed: P5.6, pic1.3 (ra1)
unnamed: P5.8, pic1.4 (ra2)
unnamed: P5.10, pic1.5 (ra3)
unnamed: P5.12, pic1.7 (ra5)
unnamed: P6.1, P6.2, pic1.21 (rd2)
unnamed: P6.3, P6.4, pic1.22 (rd3)
unnamed: P6.5, pic1.19 (rc4)
unnamed: P6.6, R3.1, pic1.20 (rc5)
unnamed: P7.3, R16.1
unnamed: P8.1, R14.1
unnamed: P8.3, R15.1
unnamed: P13.1, P13.2, R12.1, opt2.6, pic1.26 (rx)
unnamed: P16.1, pic1.10 (re2)
unnamed: P16.2, pic1.9 (re1)
unnamed: P16.3, pic1.8 (re0)
unnamed: R4.1, pic1.1 (mclr#)
unnamed: R13.1, opt2.7
unnamed: R14.2, pic1.25 (tx)
unnamed: SID1.5 (res#), SID2.5 (res#), shft1.2 (o5)
unnamed: SID1.9 (a0), SID2.9 (a0), shft1.7 (o0)
unnamed: SID1.10 (a1), SID2.10 (a1), shft1.6 (o1)
unnamed: SID1.11 (a2), SID2.11 (a2), shft1.5 (o2)
unnamed: SID1.12 (a3), SID2.12 (a3), shft1.4 (o3)
unnamed: SID1.13 (a4), SID2.13 (a4), shft1.3 (o4)
unnamed: pic1.23 (rc4), shft1.12 (rclk), shft2.12 (rclk)
unnamed: shft1.9 (o8), shft2.14 (ser)

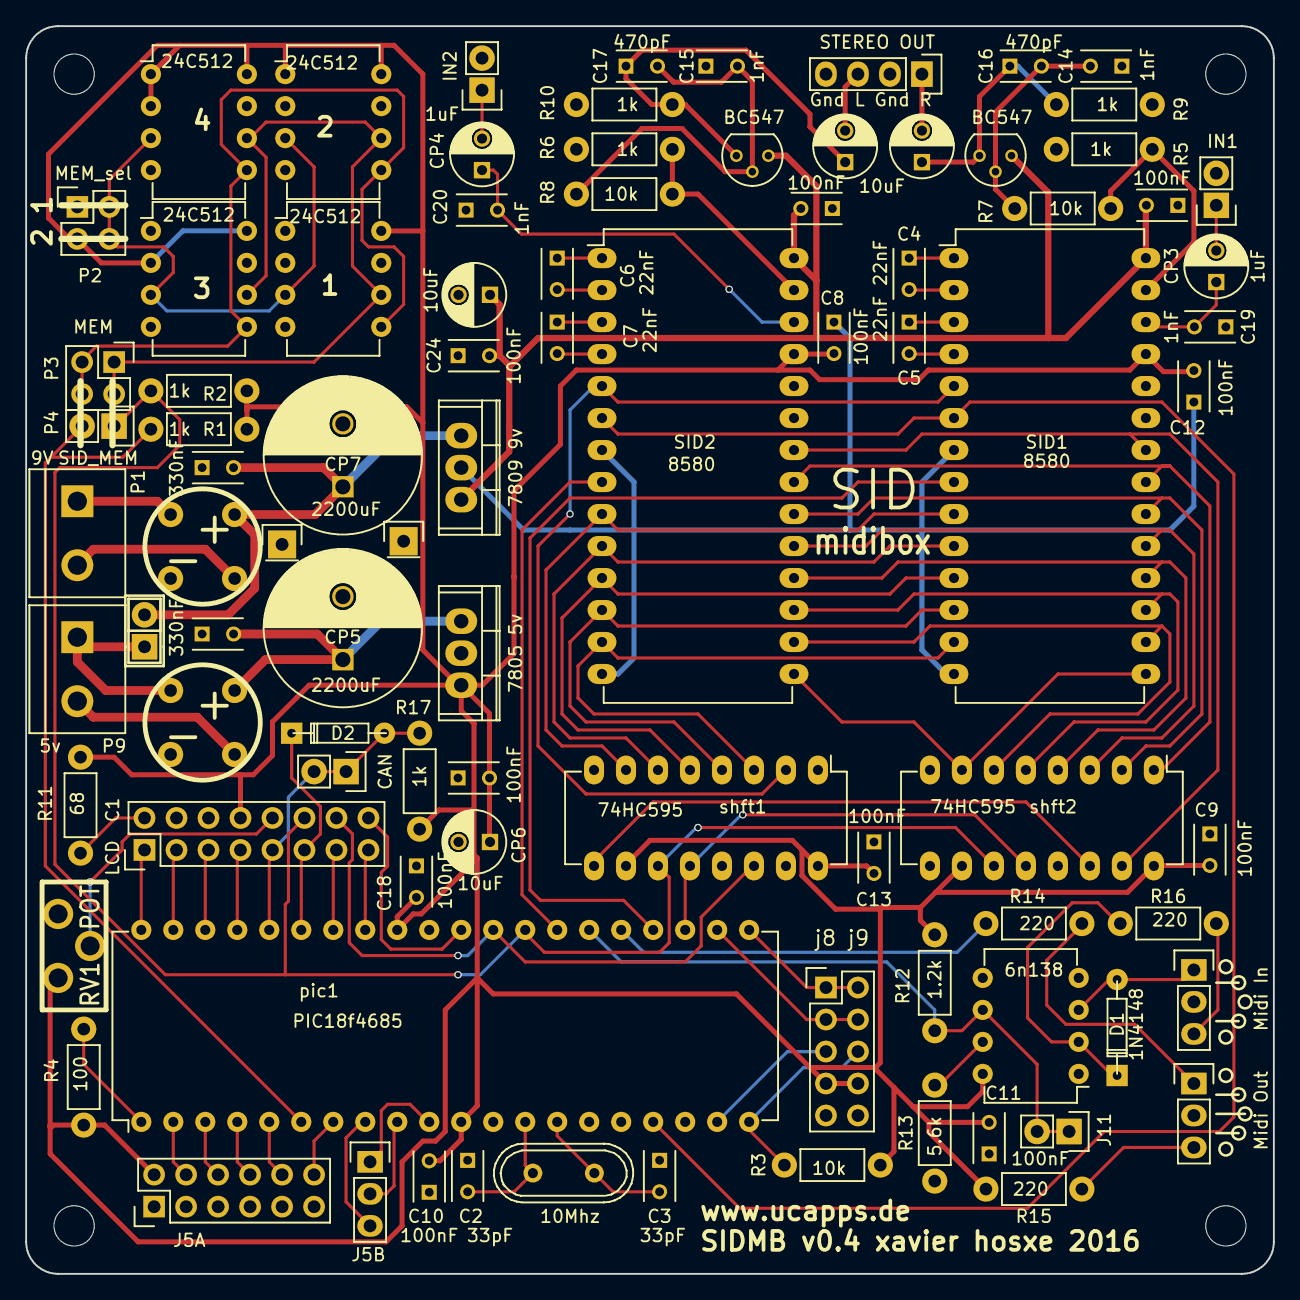
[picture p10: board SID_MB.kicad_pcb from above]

Board: 2 copper layers, 99.1 x 99.1 mm, 93 parts (0 on the bottom side), 88 nets.

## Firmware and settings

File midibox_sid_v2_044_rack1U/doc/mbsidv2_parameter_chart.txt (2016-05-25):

$Id: mbsidv2_parameter_chart.txt 1189 2014-12-19 20:00:14Z tk $

General Parameter Handling
~~~~~~~~~~~~~~~~~~~~~~~~~~

Each Engine supports up to 256 parameters which can be assigned to
following control sources:

   - Knobs, this means:
     o controllable via MIDI: CC#01 (ModWheel) and CC#16/CC#17/CC#18/CC#19
     o the 5 Knobs functions, located in OSC Assign Layer of the Control Surface
     o 5 analog inputs (to control the parameters with faders or pots)
       (DEFAULT_J5_FUNCTION must be set to 1 in your setup_*.asm file)
     o Aftertouch
     o Velocity
     o PitchBender

   - Wavetable Sequencers (Lead Engine: 4, Multi Engine: 6)

   - Bassline Sequencer (as parameter track)


The parameters are also accessible via NRPN controllers with full
resolution.

In order to achieve highest flexibility, a special address coding is
used. Here a full explanation:

The parameter value is derived from the NRPN LSB + bit #0 of the NRPN MSB.
Examples (all values in hexadecimal format):
        LSB   MSB
  B0 62 01 63 00    Selects Parameter #1
  B0 62 7F 63 00    Selects Parameter #127
  B0 62 00 63 01    Selects Parameter #128
  B0 62 7F 63 01    Selects Parameter #255

For some parameters - like Filter CutOff or Oscillator Pulsewidth - it 
is possible to separate between the left and right audio channel by
adding 2 (for left channel) or 4 (for right channel) to the MSB:

        LSB   MSB
  B0 62 04 63 00    Selects CutOff Frequency of Left and Right Audio Channel
  B0 62 04 63 02    Selects CutOff Frequency of Left Audio Channel
  B0 62 04 63 04    Selects CutOff Frequency of Right Audio Channel


NRPN Data values are 14 bit, but some MIDI controllers or Sequencers
do only support 7bit NRPN values. In addition, it has to be
considered, that the value range of MBSID parameters is different (see
specifications in the tables below)

In order to overcome such conversion issues, NRPN values can be automatically 
scaled over the full 14bit range.

This means for example: the Filter CutOff has a resolution of 12bit 
(range 0-4096), the Finetune Parameter has a resolution of 8bit (range 0-255).
The final value will always be scaled correctly over the NRPN value range 
0-16383 regardless of the final resolution, so that you don't need to take 
care about the conversion.

This even allows you to send a single NRPN data MSB event with a range of 0-127,
in order to sweep over the parameter range due to the used resolution compression
algorithm.


But if desired, it's also possible to access the parameters with
absolute values without automatic scaling. This can be achieved by setting
bit #6 of the NRPN MSB.

Examples:
        LSB   MSB
  B0 62 21 63 40    Unscaled access to OSC1 Waveform of Left and Right Audio Channel
  B0 62 21 63 42    Unscaled access to OSC1 Waveform of Left Audio Channel
  B0 62 21 63 44    Unscaled access to OSC1 Waveform of Right Audio Channel


NRPN Data Values:
So long you are using the "automatic scaling address range", data
values can either be sent with reduced 7bit resolution (provided by
most MIDI controllers and sequencers), or with full 14bit resolution.

The parameter change will take effect whenever the NRPN data MSB has
been received.

Accordingly, following streams are possible to access the CutOff of
Left/Right Audio Channel:

        LSB   MSB   dataMSB
  B0 62 04 63 00 06 <value>   Changes CutOff Frequency from decimal 0-127


        LSB   MSB    dataLSB      dataMSB   
  B0 62 04 63 00 26 <value_l> 06 <value_h>   Changes CutOff Frequency from decimal 0-16383


Last but not least a hint how to determine the parameter value in
decimal form, for the case that you don't know how to calculate with
10 fingers and 6 toes ;-)

CC# for NRPN LSB: 62h == decimal 98
CC# for NRPN MSB: 63h == decimal 99
CC# for NRPN LSB data value: 26h == decimal 38
CC# for NRPN MSB data value: 06h == decimal 6

Calculating the Address LSB:
   parameter number % 128
   (or easier: if the value is >= 128, substract 128 to get it within the range of 0-127)

Calculating the Address MSB:
   parameter number >= 128 -> then 1, else 0
   + add 2 if only left Audio Channel should be selected
   + or add 4 if only right Audio Channel should be selected
   + add 64 if an absolute value should be transmitted

Example for CutOff:
          LSB     MSB    dataMSB
  176  98   4  99   0  6 <value>   Changes CutOff Frequency from 0-127
(all values decimal)


What are "current instruments"?
~~~~~~~~~~~~~~~~~~~~~~~~~~~~~~~

Sometimes it is useful to specify a parameter number in such a way,
that the final destination depends on the selection on the control
surface, or on the MIDI channel (-> Bassline/Multi Instruments)

In order to allow this, some parameters have "current" selections.
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

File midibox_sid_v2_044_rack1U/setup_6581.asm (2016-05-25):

; $Id: setup_6581.asm 1164 2014-05-28 19:27:40Z tk $
	LIST R=DEC
;
; Prepared Setup File for 6581 SID
;


	;; BankStick Chip Select Address for "ensembles"
	;; -1: only one ensemble available, stored in internal EEPROM
	;; 0..7: CS# configuration of BankStick (Pin 1, 2 and 3)
	;; reminder for default value 7: Pin 1, 2 and 3 have connected to +5V
	;; a 32k BankStick 24LC256 is sufficient for 128 storable ensembles
	;; a 64k BankStick will also work, but doesn't increase the number of available ensembles
#define DEFAULT_ENS_BS_CS	7

	;; select default filter calibration value
	;; expecting 12bit values (0..4095)
	;; will be overwritten by ensemble setting - this is only used as default value for BankStick initialisation!
#define DEFAULT_FILTER_CALI_MIN 0
#define DEFAULT_FILTER_CALI_MAX 4095

	;; number of visible menu items on LCD
	;; use:  4 for 2x16 displays
	;;       5 for 2x20 displays
	;;      10 for 2x40 displays
#define CS_MENU_DISPLAYED_ITEMS 5
	;; NOTE: if CS_MENU_DISPLAYED_ITEMS > 5, you have to adapt the DIN settings
	;; in CS_MENU_DIN_TABLE below

	;; number of LCD lines (supported: 2 for 2x* LCDs and 4 for 4x* LCDs)
#define DEFAULT_LCD_LINES 2

	;; LCD line -> cursor offsets
#define DEFAULT_LCD_LINE_Y0	0x00
#define DEFAULT_LCD_LINE_Y1	0x40
#define DEFAULT_LCD_LINE_Y2	0x14
#define DEFAULT_LCD_LINE_Y3	0x54

	;; 1: LCD cursor will be set to current parameter position (clashes with bar graph which is enabled with DEFAULT_LCD_LINES >= 4)
	;; 0: disable this feature
#define DEFAULT_LCD_PRINT_CURSOR 0

	;; Inc/Dec buttons or rotary encoder of data entry?
	;; use:  0 if rotary encoder should be used 
	;;         (pins of encoder are defined in MIOS_ENC_PIN_TABLE)
	;;       1 if buttons should be used instead
#define CS_MENU_USE_INCDEC_BUTTONS 0

	;; 0: J5 has no function at all (analog inputs don't need to be connected to ground)
	;; 1: J5 used for analog inputs - A0..A4 control Knob#1..#5, A5..A7 are not used at all
	;; 2: J5 used as digital output (pins can be added in CS_MENU_DOUT_TABLE as "shift register #0")
	;; 3: J5 used as digital output for external switches (replacement for DEFAULT_EXT_SWITCH_DOUT, AOUT_INTERFACE_TYPE must be != 0)
#define DEFAULT_J5_FUNCTION	0

	;; DOUT/DIN shift register matrix:
	;; define the DOUT shift register (1-16) to which the cathodes are connected (common line driver)
	;; 0 disables this shift register (doesn't make much sense)
#define DEFAULT_SRM_CATHODES		8

	;; define the DOUT shift register (1-16) to which the anodes of the modulation matrix are connected
	;; 0 disables this shift register
#define DEFAULT_SRM_MODMATRIX_DOUT	7

	;; optional LED/Button Matrix (used by "Wilba's Board" to reduce number of shift registers)
	;; define the DOUT shift register (1-16) to which the anodes of the LED matrix are connected
	;; 0 disables the LED matrix function - LEDs have to be connected to individual DOUT pins
#define DEFAULT_SRM_LEDS_DOUT		0

	;; define the DIN shift register (1-16) to which the button matrix is connected
	;; 0 disables the button matrix function - Buttons have to be connected to individual DIN pins
#define DEFAULT_SRM_BUTTONS_DIN		0

	;; define the number of shift registers (1-16) in the SRIO chain (DIN/DOUT shift registers)
	;; use the number of the longest chain - e.g. 4 DOUT registers, 10 DIN registers: use 10
	;; 0 disables the SRIO chain
#define DEFAULT_SRIO_NUMBER		10


	;; define the AOUT interface which is used here:
	;;   1: one MBHP_AOUT module
	;;   2: up to 4 (chained) MBHP_AOUT_LC modules
	;;   3: one MBHP_AOUT_NG module
	;; all other values invalid!
#define AOUT_INTERFACE_TYPE 0

	;; only relevant if one or more AOUT_LC modules are used:
	;; define the resolution configuration here
	;;   0: first channel 12bit, second channel 4bit
	;;   1: first channel 8bit, second channel 8bit
	;;   2: combines M1,M2 and/or M3/M4: first channel 12bit, second channel 12bit, third channel 8bit, fourth channel ignored!
	;; all other values invalid!
#define AOUT_LC_RESOLUTION_OPTION_M1 0
#define AOUT_LC_RESOLUTION_OPTION_M2 0
#define AOUT_LC_RESOLUTION_OPTION_M3 0
#define AOUT_LC_RESOLUTION_OPTION_M4 0


	;; the 8 external switches can be routed to a DOUT shift register:
	;; 0: not used
	;; 1-16: DOUT SR#1..#16
#define DEFAULT_EXT_SWITCH_DOUT	0

	;; 0: SwinSID extensions disabled
	;; 1: SwinSID extensions enabled
#define DEFAULT_ENABLE_SWINSID 0

	;; 0: only waveform 0-8 selectable
	;; 1: waveform 0-15 selectable (e.g. for selecting additional SwinSID Waveforms)
#define DEFAULT_ENABLE_UPPER_WAVEFORMS 0

	;; assign the AOUT channels for the F2A (Filter to AOUT function) here
	;; we have 4 assignments for CutOff Left/Right and Resonance Left/Right
	;; 0 disables an assignment
#define DEFAULT_F2A_CUTOFF_L_AOUT	1
#define DEFAULT_F2A_RESONANCE_L_AOUT	2
#define DEFAULT_F2A_CUTOFF_R_AOUT	3
#define DEFAULT_F2A_RESONANCE_R_AOUT	4

	;; assign the AOUT channel for the V2A (Volume to AOUT function) here
	;; we have two assignments for the left/right SID channel
	;; 0 disables an assignment
#define DEFAULT_V2A_VOLUME_L_AOUT	5
#define DEFAULT_V2A_VOLUME_R_AOUT	6

	;; assign the AOUT channel for the P2A (Pulsewidth to AOUT function) here
	;; we have six assignments for all oscillators (left/right channel)
	;; note that there is a channel conflict between other *2A functions - adaption for your setup required!
	;; 0 disables an assignment
#define DEFAULT_P2A_OSC1_L_AOUT		5
#define DEFAULT_P2A_OSC2_L_AOUT		0
#define DEFAULT_P2A_OSC3_L_AOUT		0
#define DEFAULT_P2A_OSC1_R_AOUT		6
#define DEFAULT_P2A_OSC2_R_AOUT		0
#define DEFAULT_P2A_OSC3_R_AOUT		0

	;; assign the AOUT channel for the K2A (Key to AOUT function) here
	;; we have six assignments for all oscillators (left/right channel)
	;; note that there is a channel conflict between other *2A functions - adaption for your setup required!
	;; 0 disables an assignment
#define DEFAULT_K2A_OSC1_L_AOUT		7
#define DEFAULT_K2A_OSC2_L_AOUT		0
#define DEFAULT_K2A_OSC3_L_AOUT		0
#define DEFAULT_K2A_OSC1_R_AOUT		8
#define DEFAULT_K2A_OSC2_R_AOUT		0
#define DEFAULT_K2A_OSC3_R_AOUT		0

	;; assign the AOUT channel for the O2A (Oscillator Frequency to AOUT function) here
	;; we have six assignments for all oscillators (left/right channel)
	;; note that there is a channel conflict between other *2A functions - adaption for your setup required!
	;; note also, that with O2A enabled, the connected SIDs won't output the correct frequencies anymore
	;; 0 disables an assignment
#define DEFAULT_O2A_OSC1_L_AOUT		7
#define DEFAULT_O2A_OSC2_L_AOUT		0
#define DEFAULT_O2A_OSC3_L_AOUT		0
#define DEFAULT_O2A_OSC1_R_AOUT		8
#define DEFAULT_O2A_OSC2_R_AOUT		0
#define DEFAULT_O2A_OSC3_R_AOUT		0
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
